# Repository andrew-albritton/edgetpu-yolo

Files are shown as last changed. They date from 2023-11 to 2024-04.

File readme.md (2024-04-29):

This repository contains all relavent information concerning the development and validation of the Smart Pest Repeller Device made by Team 30 at Texas A&M University.

Group members are Michael McNeil, Melquisedec Ordonez, and Andrew Albritton.

403 Project folder also contains all presentations from 404, and some of the research notes are not up to date. If you seek current information please read our Final Report submitted on canvas.

For Model training files please see the YOLOv5 github for the Torch versions not found in this repository.

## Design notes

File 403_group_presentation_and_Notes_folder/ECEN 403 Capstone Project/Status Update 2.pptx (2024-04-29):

## Team 30: Smart Pest Repeller Bi-Weekly Update 2 Michael McNeil Andrew Albritton Melquisedec Ordonez Sponsor: Peng Hao Huang TA: Eric Robles


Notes: Michelle

## Project Summary

Pest control methods often involve a compromise by the consumer. Consumers will often have to make the choice between methods that are highly effective with safety concerns such as pesticides, or less effective methods that are much safer like ultrasonic emitters that cover limited frequency.
The smart pest repeller is designed to offer the best of both options by using a machine learning detection program to identify what type of pest is in the target area, and then emitting the correct sound frequency in order to deter the pest from the target area.

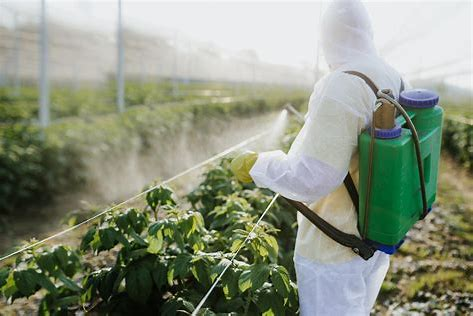
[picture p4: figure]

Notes: Kyle

## Project/Subsystem Overview

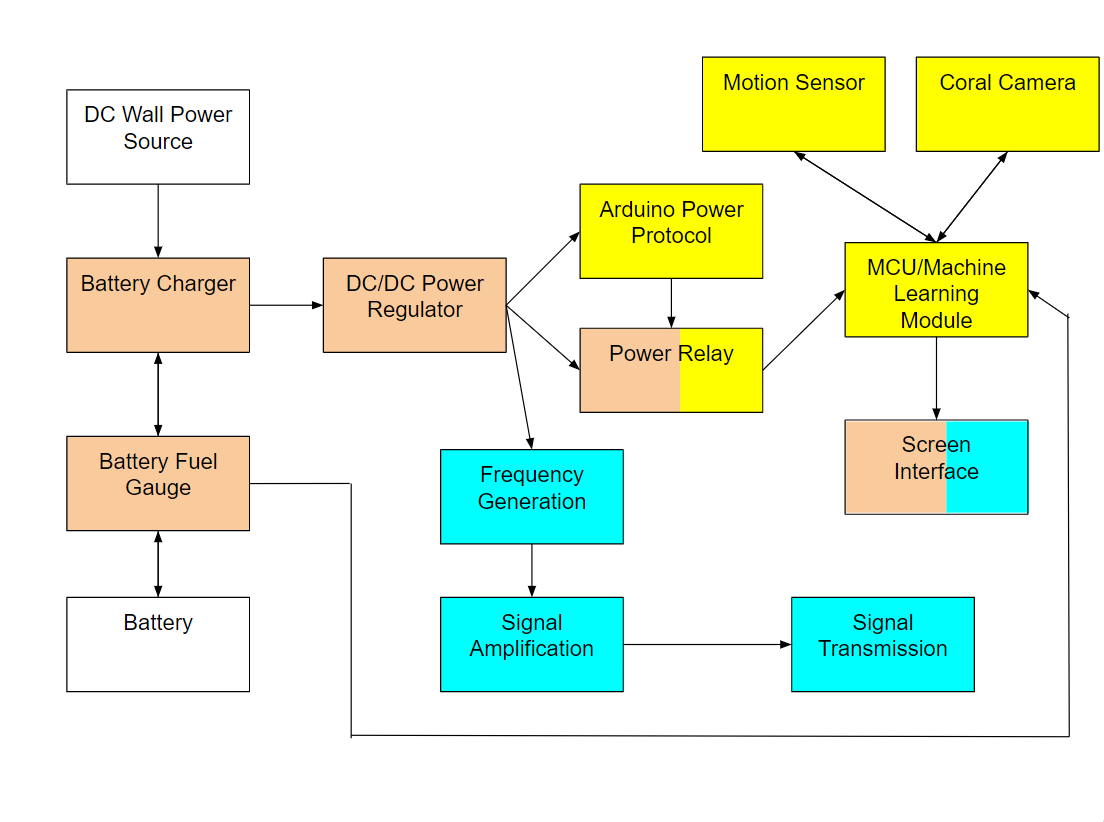
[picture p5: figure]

Michael - Orange Andrew - Yellow Mel - Blue

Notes: Eric

## Project Timeline

Subsystem Designs and Testing (to complete 2/23) | Integration of power subsystem and MCU (to complete by 2/29) | Integration of detection and emitter subsystems (to complete by 3/1) | Final Integration (to complete by 3/10) | System Test (to complete by 3/25) | Validation (to complete by 4/8) | Demo and Report (to complete by 4/15)

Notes: Eric

## Power Subsystem Michael McNeil

Accomplishments since 403 25 hrs of effort | Ongoing progress/problems and plans until the next presentation
-PCB Redesign Layout -PCB Order | PCB Assembly Subsystem Testing and Validation Start Integration with MCU

## Power Subsystem Michael McNeil

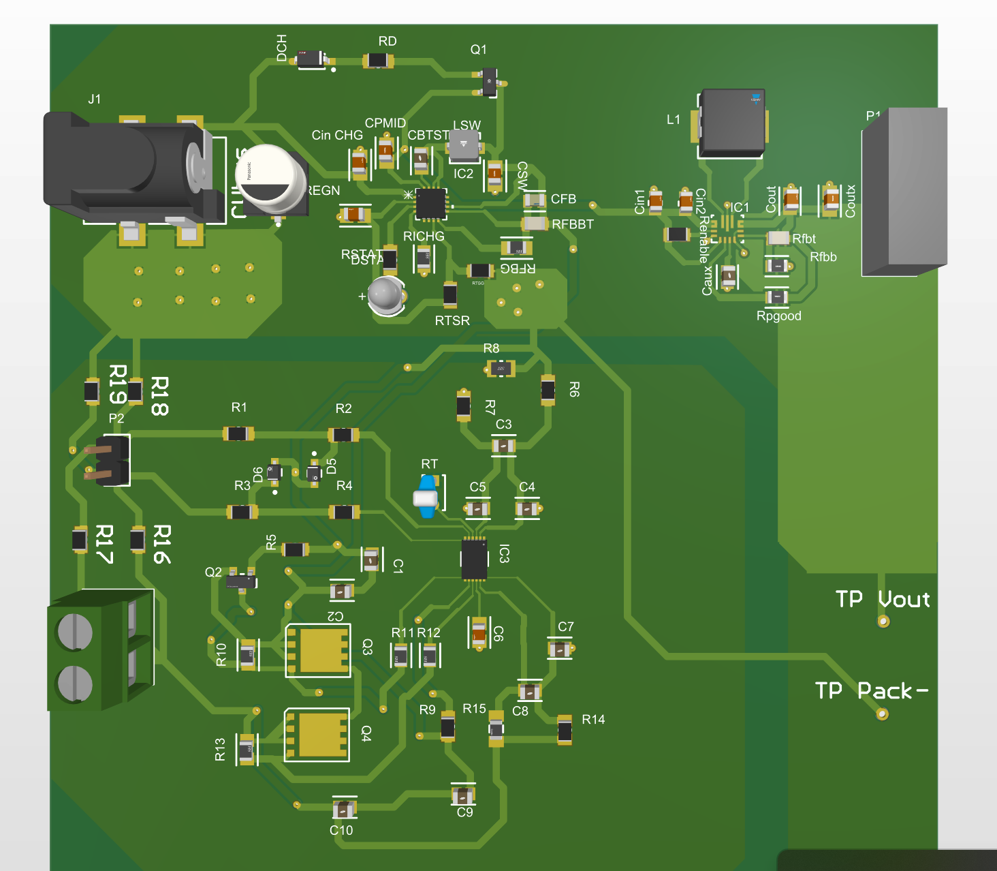
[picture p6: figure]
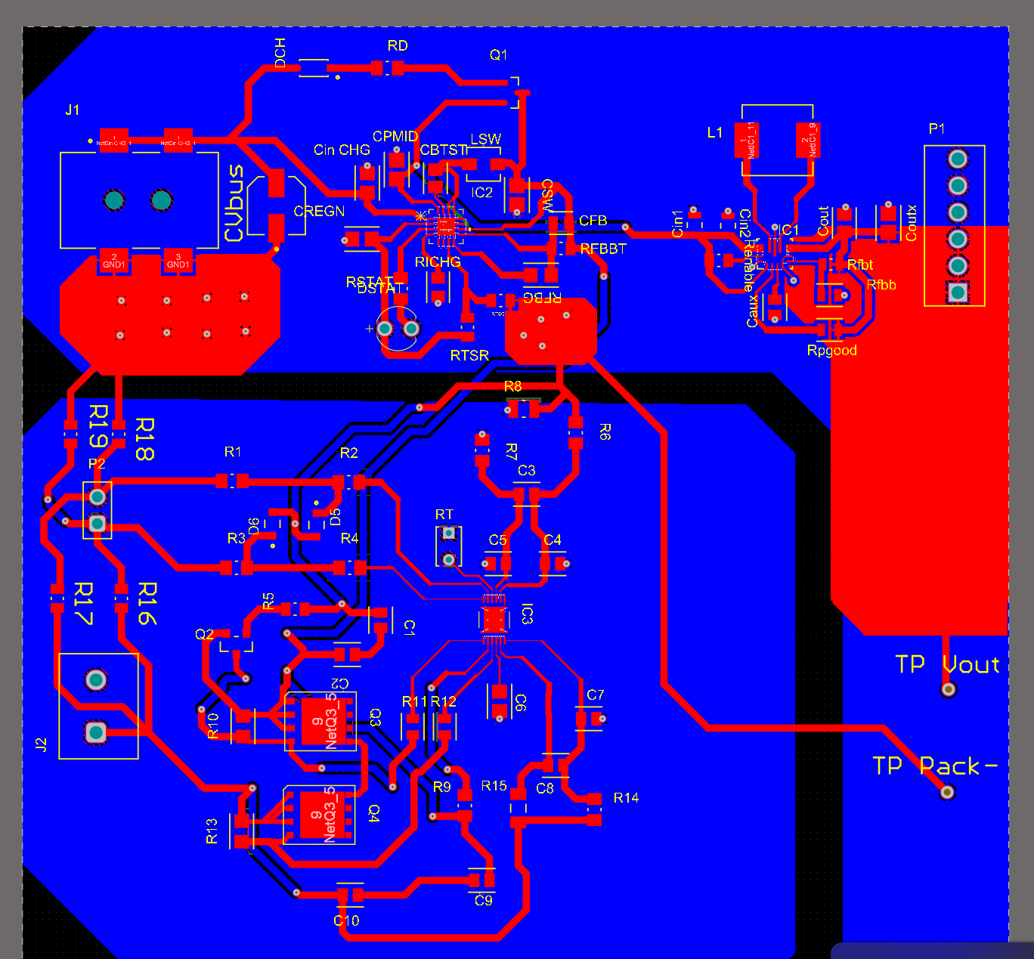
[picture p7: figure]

## ML / Control Subsystem Andrew Albritton

Accomplishments since 403 22 hrs of effort | Ongoing progress/problems and plans until the next presentation
Relay and MCU shutdown control for power system integration completed and undergoing testing Data-Set rebalanced Confusion matrix changed to integer values for more accurate validation | Model’s hyperparameters need to be adjusted in accordance with new optimizer being used. Training runs are performed over-night every day Change boot conditions of MCU, so the model will run on boot.

## ML / Control Subsystem Andrew Albritton

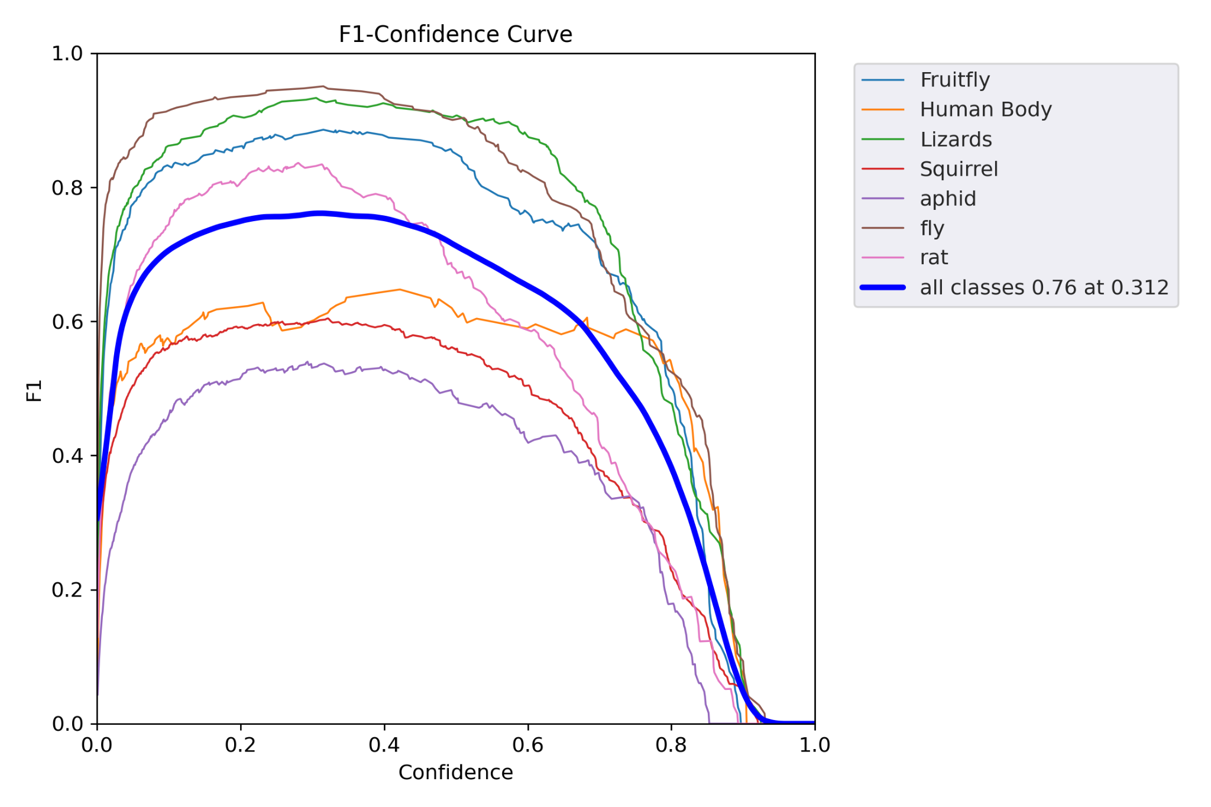
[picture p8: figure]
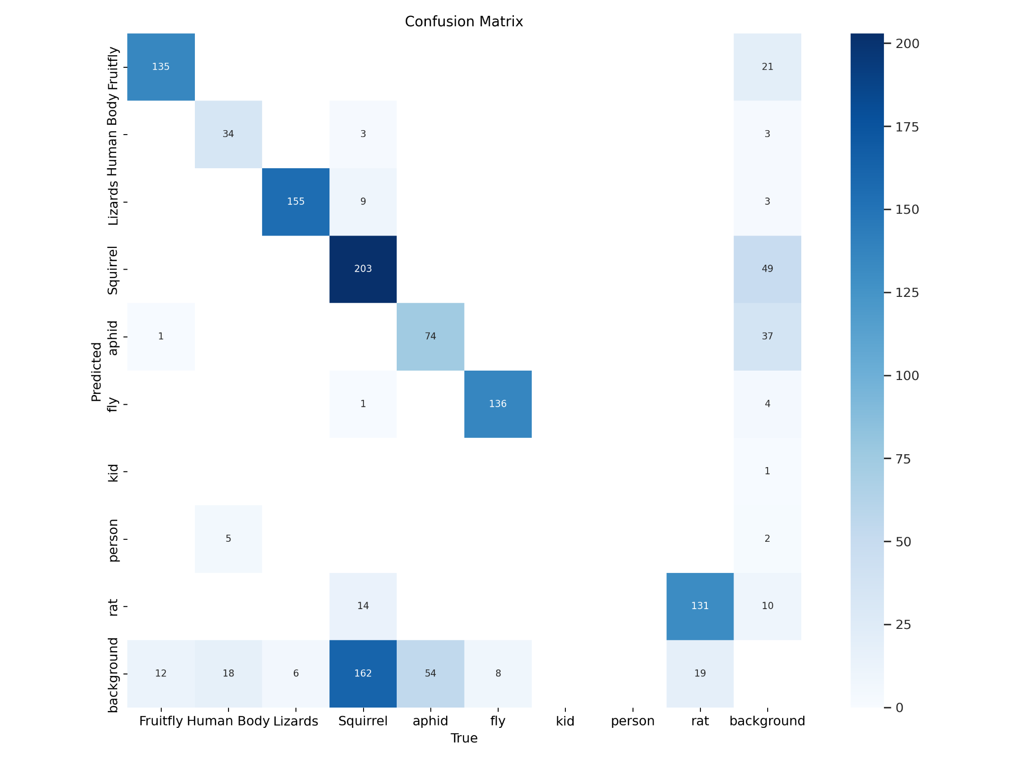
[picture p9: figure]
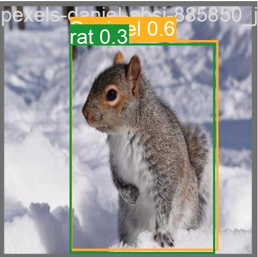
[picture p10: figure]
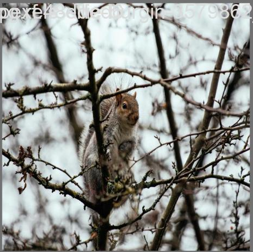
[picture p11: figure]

## Emitter Subsystem Melquisedec Ordonez

Accomplishments since 403 13 hrs of effort | Ongoing progress/problems and plans until the next presentation
Redesigned Schematic complete | Routing PCB System screen description/information Moving SPI communication to MCU

## Emitter Subsystem Melquisedec Ordonez

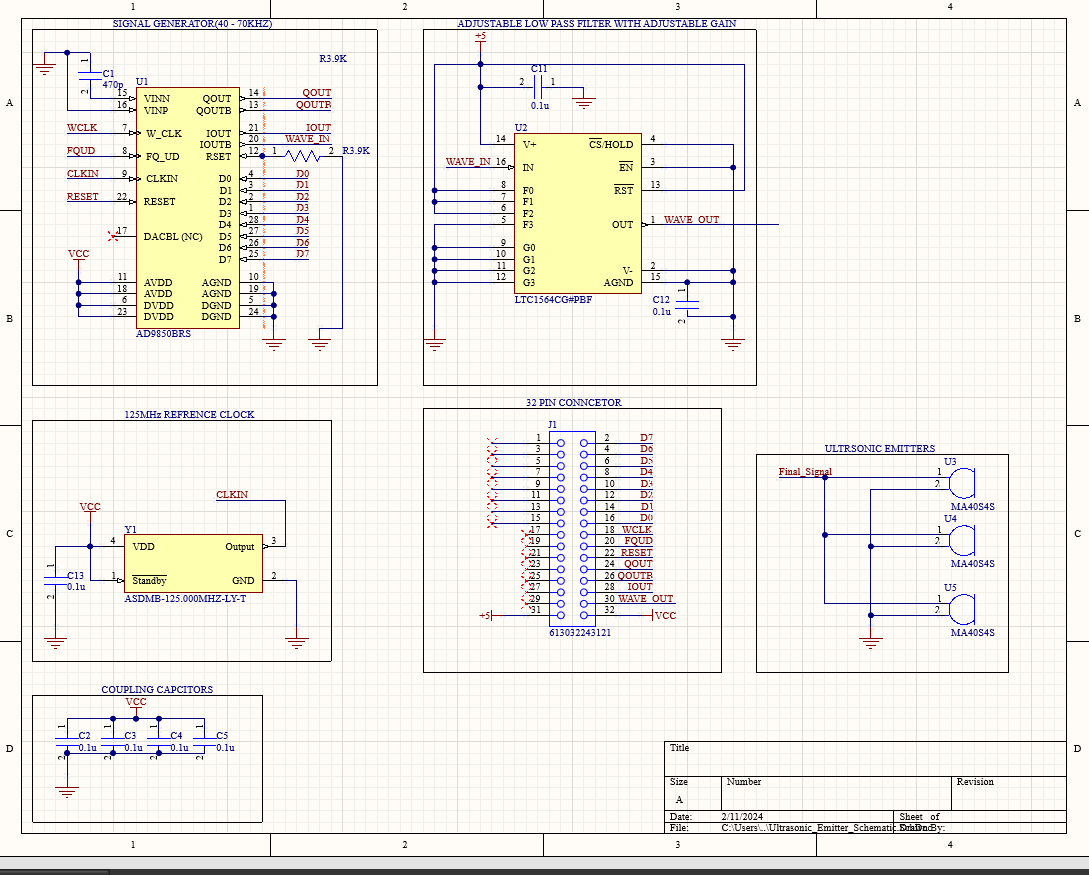
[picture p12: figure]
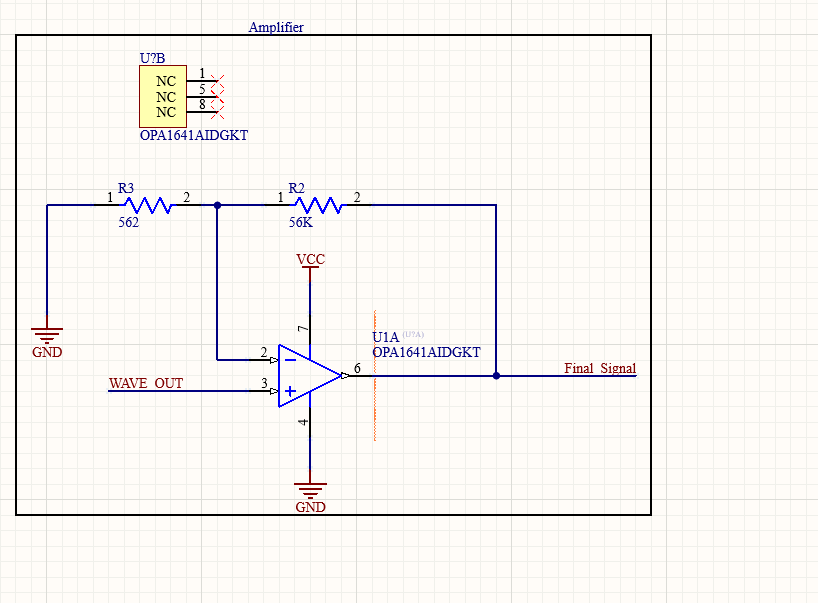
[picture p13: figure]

## Schedule

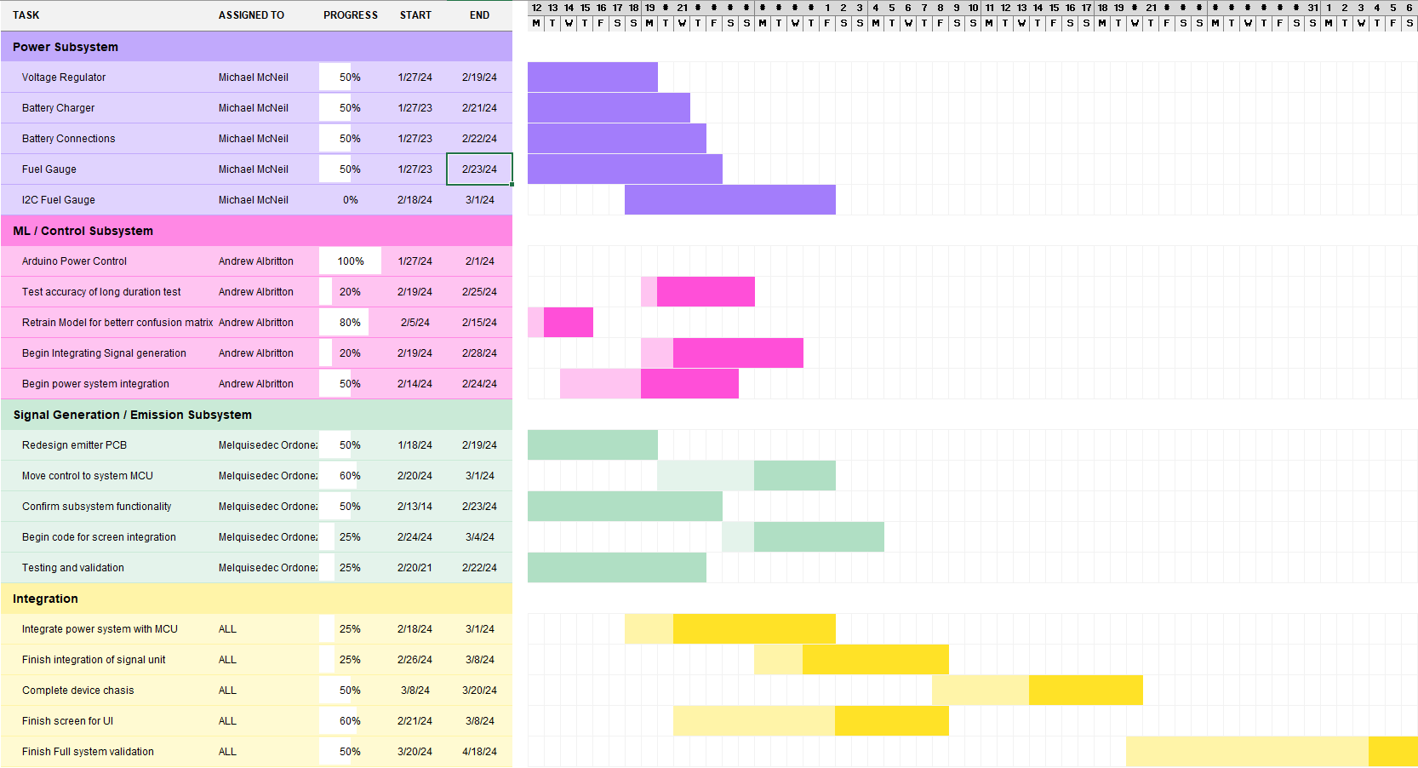
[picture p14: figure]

## Validation Plan

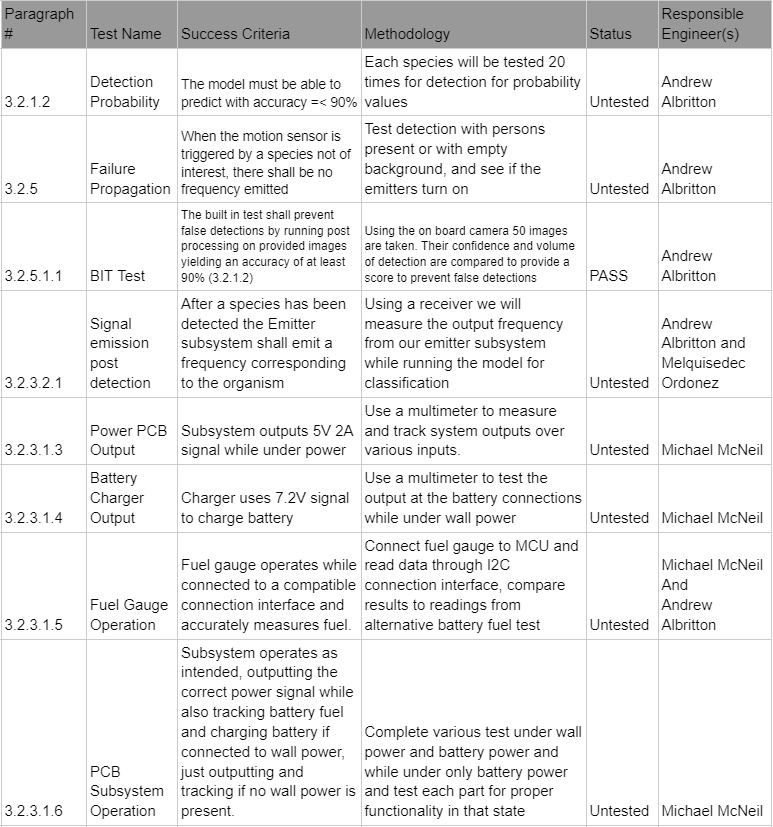
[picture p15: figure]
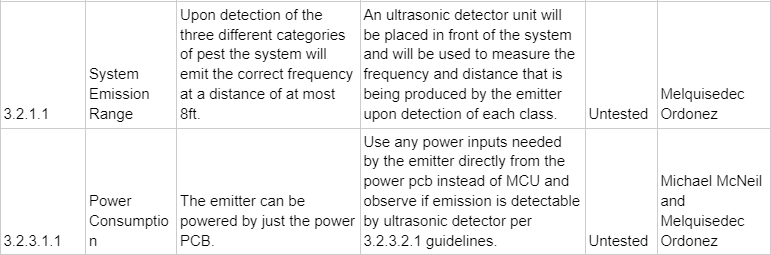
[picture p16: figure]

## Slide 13

Thank you.

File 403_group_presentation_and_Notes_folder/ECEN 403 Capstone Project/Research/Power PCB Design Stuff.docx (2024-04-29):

DC/DC Converter Start Up Simulation

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
Summary

Outline

Headings you add to the document will appear here.

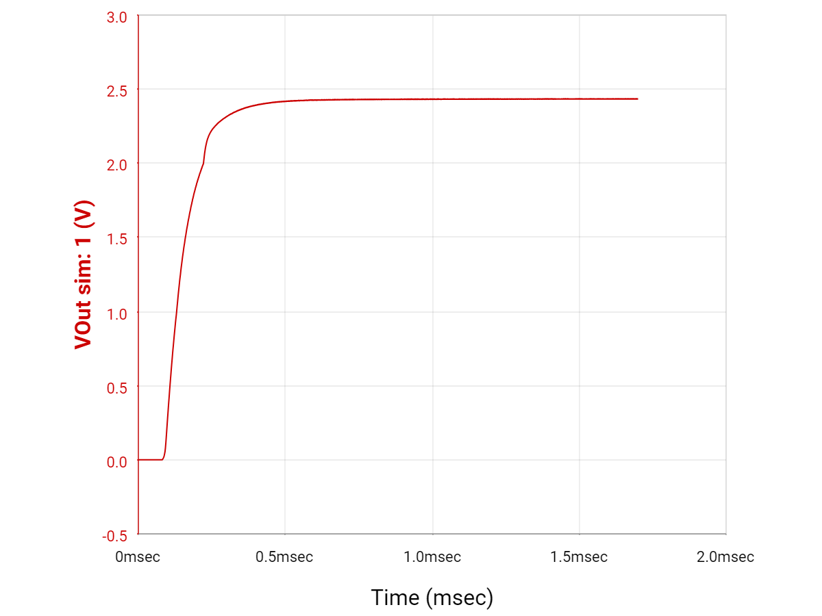
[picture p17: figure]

Start Up Time: 1.63 ms

Voltage Regulator Used for Circuit: https://www.ti.com/lit/ds/symlink/tps63070.pdf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

Battery Charger Used for Starting Design:

https://www.ti.com/lit/ds/symlink/bq24171.pdf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

DC Jack Used in Design:

https://www.cuidevices.com/product/resource/pj-002bh-smt-tr.pdf

Fuel Gauge:

https://www.ti.com/lit/ds/symlink/bq28z620.pdf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

Battery:

https://www.digikey.com/en/products/detail/jauch-quartz/LI18650JP2S2P-PCM-2-WIRES-70MM/9562752

Possible New Battery Charger -

https://www.ti.com/lit/ds/symlink/bq25306.pdf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

Fuel Gauge Technical Reference Manual - https://www.ti.com/lit/ug/sluuco9a/sluuco9a.pdf?ts=1709417492458

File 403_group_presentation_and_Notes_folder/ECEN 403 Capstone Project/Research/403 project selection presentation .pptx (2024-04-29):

## Project name: Smart Pest Repeller Team members: Andrew Albritton Michael McNeil Melquisedec Ordonez

## Executive Summary

Problem Statement:
- Pest control is a issue that often makes people choose between environmentally harmful solutions or solutions that are not very effective.
- Pest control models that do not use harmful chemicals or pesticides, often are ineffective due to the limited range of frequencies they can generate (different pests respond to different frequencies)
Solution Proposal:
- Our device will utilize an image based ML model in order to classify between three different subgroups of organisms in order to allow for repelling flies, rodents, and lizards.
- Once one of the listed organisms is recognized the sound system will emit the corresponding frequency of the recognized organism.

## Diagram of subsystems and interface

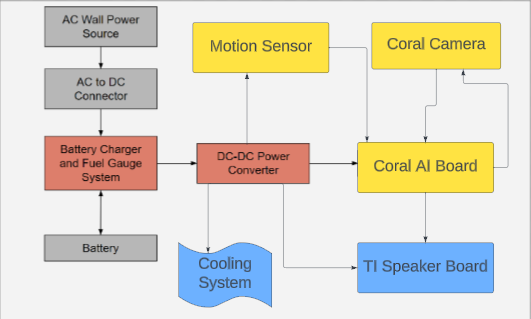
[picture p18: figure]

Red / Grey: Michael McNeil
Yellow: Andrew Albritton
Blue: Melquisedec Ordonez

## Task Partition

Andrew: ML image classification, camera operations and motion sensor
Michael: Power supply and battery system
Melquisedec: Ultrasonic emitter and cooling system

## Machine Learning Image Recognition -

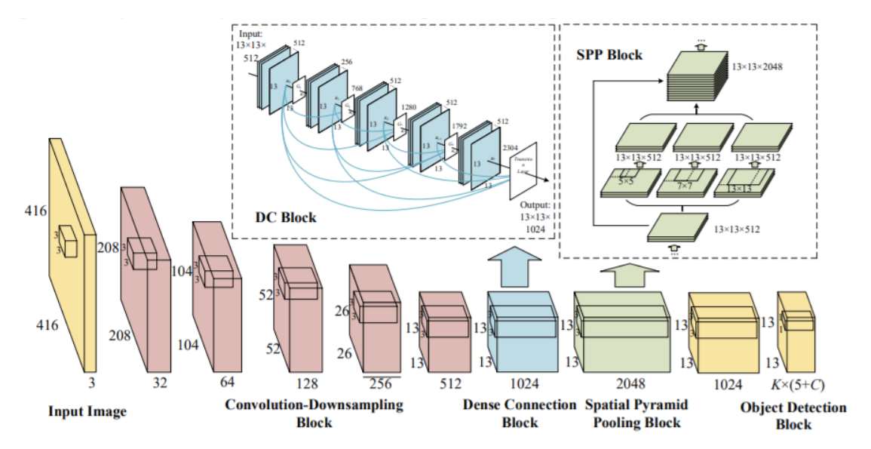
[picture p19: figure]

- A motion sensor when triggered will activate a camera attached to the Coral board.
- This image will result in one of the four following labels: Rodent, Lizard, Fly, or ignore.
- The ignore label will prevent the speakers from activating when the motion sensor is triggered by a person, dog, bird, etc.
- We will be using the YOLO git repository to create and test our model. A figure of YOLO’s algorithm can be found in the top right hand corner

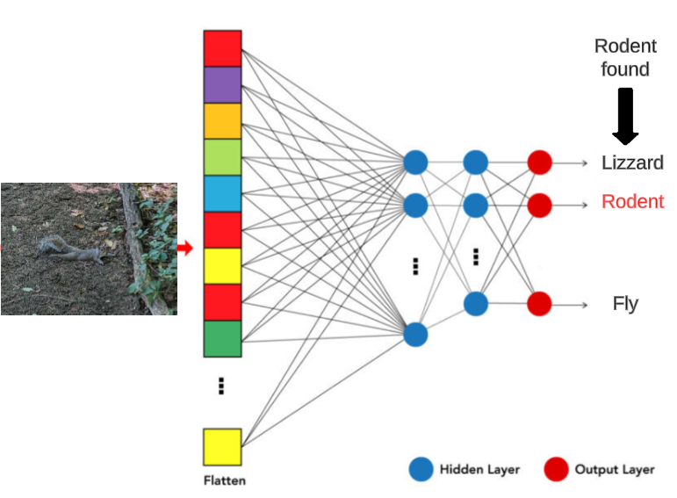
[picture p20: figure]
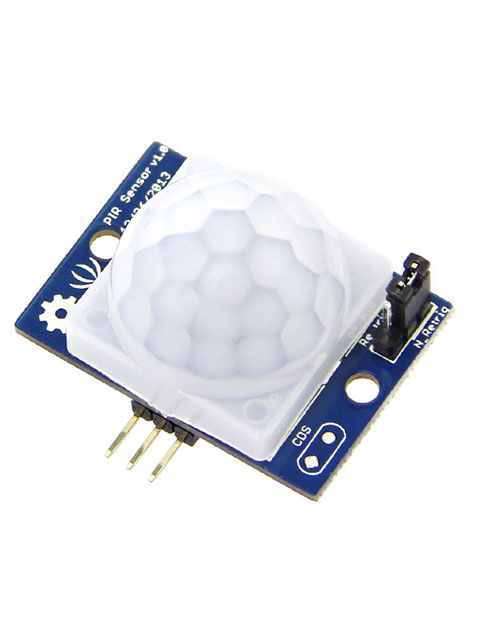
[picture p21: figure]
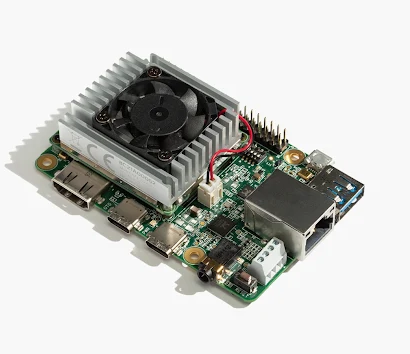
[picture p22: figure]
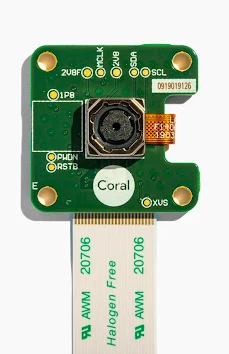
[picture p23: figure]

## Power System

Wall Power Mode:
- System, when connected to wall power, will power the main microcontrollers while charging the battery
- Battery charging circuit will monitor fuel level of battery in order to prevent overvoltage and potential damage to the battery
Battery Mode:
- System, when disconnected from wall power, will operate via battery power
- System will include a fuel gauge to indicate to user when it is time to charge the system again.

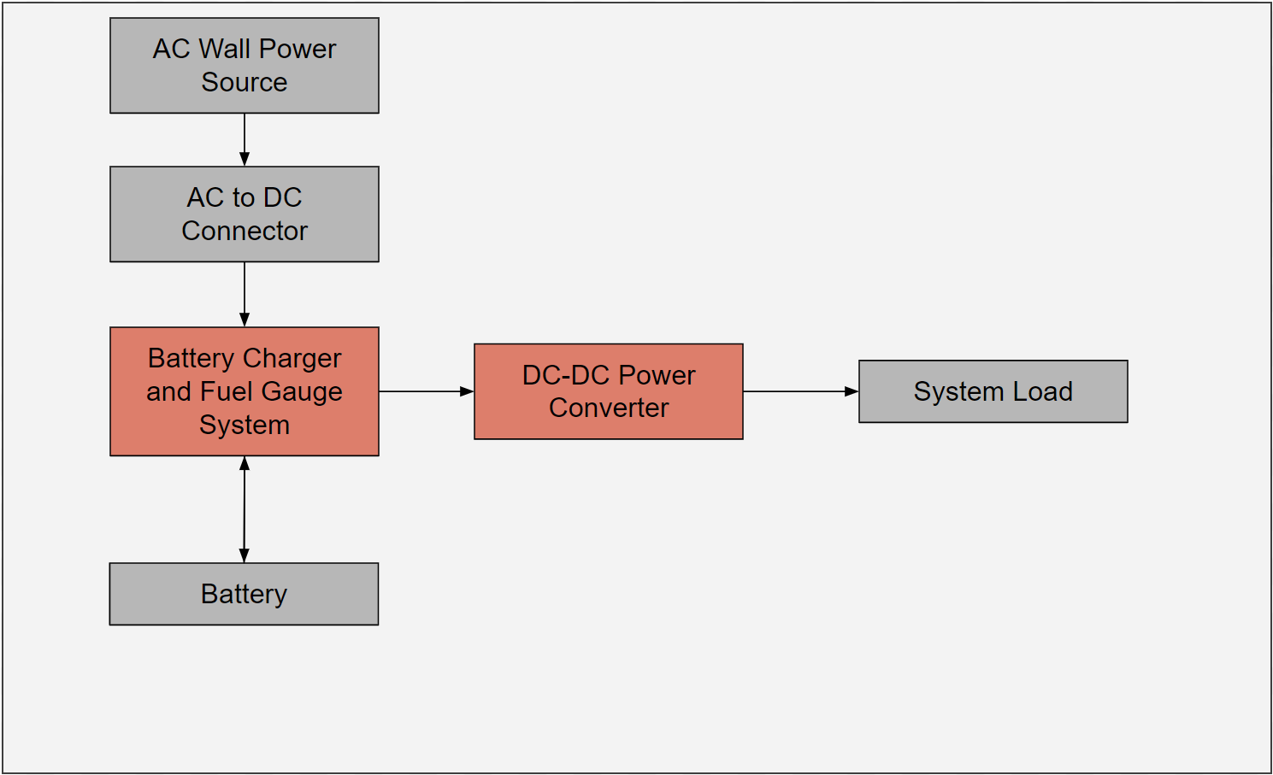
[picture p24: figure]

## Sound/Cooling System

- Transmitter emmitts ultrasonic sound sensitive to the particular pest detected by camera, eg insect or rodent.
- Humidity sensor detects when humidity levels are beyond operating range of devices
- Fan keeps system units dry to keep them operational on hotter or wet conditions.

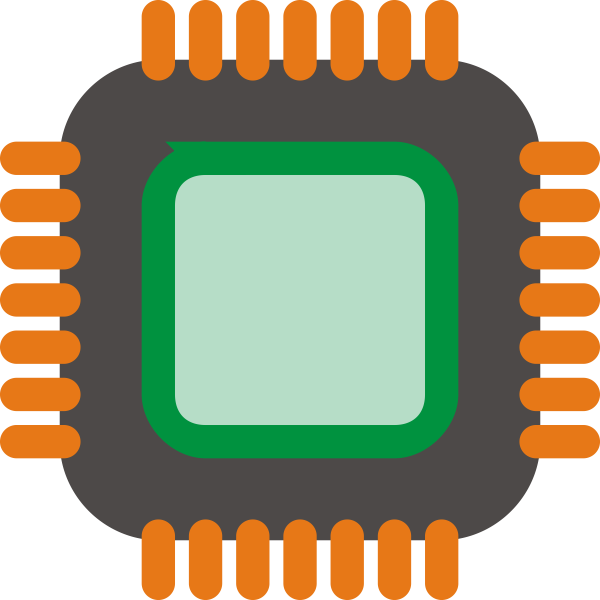
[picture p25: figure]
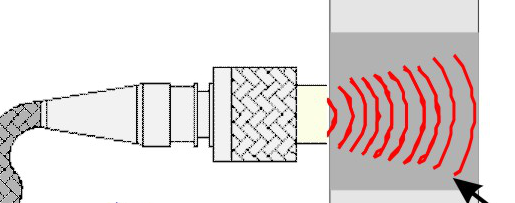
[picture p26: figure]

## Execution and Validation plan

Currently: have outlined needs for each system, assembled partial parts list, begun preliminary subsystem designs

| October 14th | October 28th | November 14th | November 25th
Machine Learning Image Model, Camera, and Motion sensor | -Finish putting together YOLO training algorithm -Start working on training | -Finish Training, and test for a goal of >=90% precision -Begin model implementation on Coral Board | -Finish Camera program .py configuration -Install Motion sensor, and test camera -Ensure proper program speed | -Finish testing the built model using the camera and motion sensor
Power Delivery / Management | -Finalize PCB Design -Run simulations -Order Parts | -Learn to solder -Start to assemble PCB circuitry | -Finish PCB implementation -Start testing and debug | -Finish test and debug -Validate system
Sound/Cooling System | - Final system parts delivered -System design completed | -Validate/Stress test individual components | -Begin on integration of individual parts | -Stress test integrated parts

## Questions?

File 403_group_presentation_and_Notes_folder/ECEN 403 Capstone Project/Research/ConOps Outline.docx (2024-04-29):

Smart Pest Repeller

Andrew Albritton

Melquisedec Ordonez

Michael McNeil

Concept of Operations

1. Executive Summary

Controlling the presence of pests is a task that can be a struggle for various different aspects of life. The goal of the Smart Pest Repeller is to address this issue as easily as possible for users while also mitigating potential hazards that come with alternative methods of pest control. The Smart Pest Repeller will utilize a camera and machine learning program in order to sense the presence of pests in the area through image processing. This will send a signal to an ultrasonic sound emitter that would activate to repel any pests that were sensed. The repeller will be able to function while plugged into a wall or on its own in order to maximize effective use situations. This will decrease the manpower and resources needed to address pest control in commercial, agricultural, and residential settings.

2. Introduction
  a. Background

The Smart Pest Repeller’s goal is to improve over what currently is the standard of the pest repellant industry, which is either the use of harsh chemicals or a similar system of ultrasonic sound that does not have an ability to detect pests, so it will always be activated and emitting sound. Some sound based repellers on the market do have sensing technology in place but none of it is image based, instead using motion sensing which will still activate in the presence of people or pets in the home or surrounding area. The Smart Pest Repeller is designed to be the environmental and pet friendly solution to pest problems.

The current standard for pest control employed by most residential or commercial users currently is either the use of pesticides and other harsh chemicals or the implementation of different ultrasonic sound systems than the Smart Pest Repeller system. The limitations and drawbacks of these methods is what we are seeking to address with the Smart Pest Repeller. Since SPR is using image processing sensing technology to identify pests, it will not activate in the presence of humans or other pets and will instead target specifically pests. This solution will mitigate the need for harsh chemical pesticides while also introducing a solution that targets specifically pests and does not act as a hindrance to anything else.

  b. Overview

The system will use a camera connected to a controller unit that will be running a program to process the images received. When the program reads that there is a pest detected in the image it will send a signal to the ultrasonic sound emitting device that will act as the pest control mechanism. Once the pest is no longer detected in the area the system will turn off the sound emitter and wait until another pest is detected. The unit will be able to plug into the wall and run directly from wall power or be able to function disconnected from the wall on battery power as well.

  c. Referenced Documents and Standards
- Rechargeable Battery Standards - Lithium, Nickel Metal Hydride, Nickel Cadmium (epectec.com) (https://www.epectec.com/batteries/battery-standards.html)
- OSHA Speaker/Workplace sound OSHA Technical Manual (OTM) - Section III: Chapter 5 | Occupational Safety and Health Administration (https://www.osha.gov/otm/section-3-health-hazards/chapter-5)
3. Operating Concept
  a. Scope

Our proposed repeller will be designed primarily for outdoor use in agricultural settings, small gardens or farms. It will be able to detect medium to larger insects in addition to smaller reptiles. The repeller will not be able to detect small insects such as mosquitos or small flies and will therefore not repel these. As our repeller will use a camera for detection it will not work at night or other times of low light visibility. The repeller will have a battery that will need to be charged so it will occasionally be limited to near the home or make use of an extension cable for uses away from the home while charging.

  b. Operational Description and Constraints

The repeller will be used outdoors in a well lit environment. The repeller will use a camera that captures an image of the environment about once every second and send it to a microcontroller. This will be sent to an image detection system that determines if there are any pests in the frame. If a pest has been identified in a frame the microcontroller will send a signal to a speaker that will emit an ultrasonic soundwave to repel the pest. Once a pest is out of frame the speaker stops emitting and waits until it receives a new signal to begin emitting again.

The smart repeller will be limited to environments with decent to high light exposure and will not work during times of low light visibility, night or moments with overcast for example.

  c. System Descriptions

The smart pest repeller will consist of three major components; the power unit, the camera and ultrasonic transmitter interface, and the microcontroller.

The power unit can operate either plugged into a traditional wall outlet or independently with a battery. While plugged into a wall outlet, the microcontroller and sensors will receive power directly from the wall and will also charge the battery if neeeded. If not connected to a wall outlet the battery will take over and send power to all the systems.

The camera is controlled by a python program on the Coral board. This program will be automated to take a photo at 1 frame per second. The microcontroller will use a ML algorithm to classify objects in the image. The four choices of classification or labels for the model will be: Flies, Lizards, Rodents, and Idle. Each time an image is done processing one of the above modes will be active.


Fig 1.1

  d. Modes of Operation

Our power system will have 2 modes of operation, wall power or battery power at 5V 2-3A draw. The rest of our system will have 4 modes of operation. Three of the modes are listed in Fig 1.1 as speakers, but the fourth mode will be an idle mode where the speaker systems are turned off. The speaker being used will be marked by an LED of color corresponding to the speaker frequency.

  e. Users

The Smart Pest Repeller could be marketed to any group of individuals from the individual homeowner to the commercial farmer. This is a great solution to pest control in small areas and could be deployed to cover much larger areas if multiple devices are used. It will act as an eco-friendly solution to the everyday pest problems that users may encounter.

  f. Support

Support for the Smart Pest Repeller will come in the form of a manual that will describe how the system works and how to operate it as well as a brief description of each subsystem in place in the system for troubleshooting purposes.

4. Scenarios
  a. Garden or Outdoor Area Use

The Smart Pest Repeller will be best suited to smaller outdoor areas or gardens. This will be an ideal location for the SPR as the camera system will have a hard time sensing pests the farther they are away so this system will be optimized for use in locations such as backyard gardens or lounge areas. The system will do great in these settings as it will likely be checked on by users more frequently than a device that is just left in the field so charging will be common enough to not be an issue. The system will also not target any pets that could be a concern for the user.

  b. Commercial Agriculture

The Smart Pest Repeller could also be used on bigger portions of land that would be used in farming operations but the amount of devices used may vary depending on the size of the land. Since the camera can only see so much in detail it will be more difficult to apply the camera sensing technology to a larger farm setting but if there are multiple systems in place that are strategically located, the system results should be similar to the results of using one device in a smaller area.

5. Analysis
  a. Summary of Proposed Improvements

The recent models of “Smart Pest Repellers” are motion based, or constantly emit high frequency sound. Our device will utilize a deep learning algorithm which will differentiate between undesirable and desirable organisms. For example, a bee pollinating your garden is desirable, while a grasshopper would damage fauna. We would want to allow bees to pollinate, but if there are undesirable organisms present we will turn the high frequency emitter on.

  b. Disadvantages and Limitations

The disadvantages of the Smart Pest Repeller system is that since the system will be constantly running a machine learning algorithm for image processing, there will be a significant increase in power needs for the system to function. The system will also be less effective at night time since it is using image processing to detect pests and at night the camera visibility will decrease drastically. The system will also be contained in a housing unit that will take up more space than the alternative solutions such as plug-ins or citronella candles.

  c. Alternatives

Many alternatives to the Smart Pest Repeller already exist on the market but each of these has different limitations of their own. Pesticides are a very common solution to the pest problem, but they also have significant drawbacks in the form of polluting the environment and also exposing unintended organisms to harmful chemicals such as other humans and pets. Other ultrasonic sound repellent systems also exist but they have limitations such as always emitting sound having to be plugged into a wall power outlet, or always emitting the same frequency (lizards, rodents, and flies react to separate frequencies: 52-60kHz, 60-72kHz, and 38-44kHz respectively)

  d. Impact

For the average gardener, our device will provide protection from not only flies, but rodents and lizards as well. We will be using our machine learning algorithm to differentiate between the animals listed above; this allows for differing frequency outputs from our sound source, allowing for effective pest control from most possible invaders. It can also be noted with other devices, organisms become accustomed to the constant presence of high frequency sound over time causing the device to lose its effectiveness. Our device will only trigger while there is a pest detected, this allows for an irregular pattern of sound, thus causing adaptation to the device to become more difficult for pests. High frequency pest control is considered one of if not the most humane method of pest control currently, and our device will allow for a broader range of application than the devices currently on the market.

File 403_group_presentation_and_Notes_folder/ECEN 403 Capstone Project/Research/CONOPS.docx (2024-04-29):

Smart Pest Repeller

Andrew Albritton

Mequisedec Ordonez

Michael McNeil

Concept of Operations

REVISION

14 September 2023

Concept of Operations

for

Smart Pest Repeller

Team 30

Approved by:

_____________________________

Project Leader Date

_____________________________

Prof. Kalafatis Date

_____________________________

T/A Date

Change Record

Rev. | Date | Originator | Approvals | Description
0 | 9/12/23 | ALL | | Draft Release
1 | 9/28/23 | ALL | | Midterm Report ICD & FSR additions

Table of Contents

Table of Contents 3

List of Tables 4

List of Figures 5

1. Executive Summary 6

2. Introduction 7

2.1. Background 7

2.2. Overview 7

2.3. Referenced Documents and Standards 7

3. Operating Concept 8

3.1. Scope 8

3.2. Operational Description and Constraints 8

3.3. System Description 8/9

3.4. Modes of Operations 9

3.5. Users 9

3.6. Support 9

4. Scenarios 9

4.1. Garden or Small Outdoor Area Use 9/10

4.2. Commercial Use……………………………………………………………………………10

5. Analysis 10

5.1. Summary of Proposed Improvements 10

5.2. Disadvantages and Limitations 10

5.3. Alternatives 10

5.4. Impact 11

List of Tables

No table of figures entries found.

List of Figures

# Fig 1.1 - Subsystem Operational Flow Chart

# 1. Executive Summary

Controlling the presence of pests is a task that can be a struggle for various different aspects of life. The goal of the Smart Pest Repeller is to address this issue as easily as possible for users while also mitigating potential hazards that come with alternative methods of pest control. The Smart Pest Repeller will utilize a camera and machine learning program in order to sense the presence of pests in the area through image processing. This will send a signal to an ultrasonic sound emitter that would activate to repel any pests that were sensed. The device will be able to function while plugged into a wall or on its own in order to maximize effective use situations. This will decrease the manpower and resources needed to address pest control in commercial, agricultural, and residential settings.

# 2. Introduction

There are many pest control options on the market. Each of these options have some negative aspects that consumers may need to consider when deciding how to approach their pest control problems. The goal of the Smart Pest Repeller is to create the best solution to these problems while mitigating potentially negative aspects of pest control.

## 2.1. Background

The current standard for pest control employed by most residential or commercial users currently is either the use of pesticides and other harsh chemicals or the implementation of different ultrasonic sound systems than the Smart Pest Repeller system. The limitations and drawbacks of these methods is what we are seeking to address with the Smart Pest Repeller. Since SPR is using image processing sensing technology to identify pests, it will not activate in the presence of humans or other pets and will instead target specific pests. This solution will mitigate the need for harsh chemical pesticides while also introducing a solution that targets specific pests and does not act as a hindrance to anything else.

## 2.2. Overview

The system will use a camera connected to a controller unit that will be running a program to process the images received. When the program reads that there is a pest detected in the image it will send a signal to the ultrasonic sound emitting device that will act as the pest control mechanism. Once the pest is no longer detected in the area the system will turn off the sound emitter and wait until another pest is detected. The unit will be able to plug into the wall and run directly from wall power or be able to function disconnected from the wall on battery power as well.

## 2.3. Referenced Documents and Standards

- Rechargeable Battery Standards - Lithium, Nickel Metal Hydride, Nickel Cadmium (epectec.com) (https://www.epectec.com/batteries/battery-standards.html)
- OSHA Speaker/Workplace sound OSHA Technical Manual (OTM) - Section III: Chapter 5 | Occupational Safety and Health Administration (https://www.osha.gov/otm/section-3-health-hazards/chapter-5)

# 3. Operating Concept

## 3.1. Scope

The proposed system will be designed primarily for outdoor use in agricultural settings, small gardens or farms. It will be able to detect medium to larger insects in addition to smaller reptiles. The camera will not be able to detect small insects such as mosquitos or small flies and will therefore not repel these. The camera will also limit when the device can be used since during night time and in low light environments visibility will be an issue for the camera used for detection. The device will have a battery that will need to be charged so it will occasionally be limited to near the home or make use of an extension cable for uses away from the home while charging.

## 3.2. Operational Description and Constraints

The repeller will be used outdoors in a well-lit environment. The repeller will use a camera that captures an image of the environment about once every second and send it to a microcontroller. This will be sent to an image detection system that determines if there are any pests in the frame. If a pest has been identified in a frame the microcontroller will send a signal to a speaker that will emit an ultrasonic soundwave to repel the pest. Once a pest is out of frame the speaker stops emitting and waits until it receives a new signal to begin emitting again.

The smart repeller will be limited to environments with decent to high light exposure and will not work during times of low light visibility, at night or moments with overcast for example.

## 3.3. System Description

The Smart Pest Repeller will consist of three major components; the power unit, the camera and ultrasonic transmitter interface, and the microcontroller.

The power unit can operate either plugged into a traditional wall outlet or independently via a rechargeable lithium-ion battery system. While plugged into a wall outlet, the system will be able to run while also charging the battery for possible wireless use in the future. If not connected to a wall outlet the battery will continue to power the system, the system will also keep track of the fuel levels of the battery and alert the user when a recharge is needed for the battery system.

The camera is controlled by a python program on the Coral board. This program will be automated to take a photo at 1 frame per second. The microcontroller will use a machine learning, ML, algorithm to classify objects in the image. The four choices of classification or labels for the model will be: Flies, Lizards, Rodents, and Idle. Each time an image is done processing one of the above modes will be active.


Fig 1.1

## 3.4. Modes of Operations

The system will have one mode of operation and that will simply be “active”. In active mode the system will continuously run the camera and take in data that will be processed in real time to see if there is a pest present. Once the system detects a pest in the target area the emitter will turn on in order to remove pests from the area. Once the camera no longer detects the presence of pests, the system will turn off the emitter and continue to monitor for pests in the target area.

## 3.5. Users

The Smart Pest Repeller could be marketed to any group of individuals from the individual homeowner to the commercial farmer. This is a great solution to pest control in small areas and could be deployed to cover much larger areas if multiple devices are used. It will act as an eco-friendly solution to the everyday pest problems that users may encounter.

## 3.6. Support

Support for the Smart Pest Repeller will come in the form of a manual that will describe how the system works and how to operate it as well as a brief description of each subsystem in place in the system for troubleshooting purposes.

# 4. Scenario(s)

## 4.1. Garden or Small Outdoor Area Use

The Smart Pest Repeller will be best suited to smaller outdoor areas or gardens. This will be an ideal location for the SPR as the camera system will have a hard time sensing pests the further they are away so this system will be optimized for use in locations such as backyard gardens or lounge areas. The system will do great in these settings as it will likely be checked on by users more frequently than a device that is just left in the field so charging will be common enough to not be an issue. The system will also not target any pets that could be a concern for the user.

## 4.2. Commercial Agriculture

The Smart Pest Repeller could also be used on bigger portions of land that would be used in farming operations but the amount of devices used may vary depending on the size of the land. Since the camera can only see so much in detail it will be more difficult to apply the camera sensing technology to a larger farm setting but if there are multiple systems in place that are strategically located, the system results should be similar to the results of using one device in a smaller area.

# 5. Analysis

## 5.1. Summary of Proposed Improvements

The recent models of “Smart Pest Repellers” are motion based, or constantly emit high frequency sound. Our device will utilize a machine learning algorithm which will differentiate between undesirable and desirable organisms. For example, a bee pollinating your garden is desirable, while a grasshopper would damage fauna. We would want to allow bees to pollinate, but if there are undesirable organisms present we will turn the high frequency emitter on.

## 5.2. Disadvantages and Limitations

The disadvantages of the Smart Pest Repeller system is that since the system will be constantly running a machine learning algorithm for image processing, there will be a significant increase in power needs for the system to function. The system will also be less effective at night time since it is using image processing to detect pests and at night the camera visibility will decrease drastically. The system will also be contained in a housing unit that will take up more space than the alternative solutions such as plug-ins or citronella candles.

## 5.3. Alternatives

Many alternatives to the Smart Pest Repeller already exist on the market but each of these has different limitations of their own. Pesticides are a very common solution to the pest problem, but they also have significant drawbacks in the form of polluting the environment and also exposing unintended organisms to harmful chemicals such as other humans and pets. Other ultrasonic sound repellent systems also exist but they have limitations such as always emitting, sound having to be plugged into a wall power outlet perpetually, or always emitting the same frequency (lizards, rodents, and flies react to separate frequencies: 52-60kHz, 60-72kHz, and 38-44kHz respectively)

## 5.4. Impact

For the average gardener, our device will provide protection from not only flies, but rodents and lizards as well. We will be using our machine learning algorithm to differentiate between the animals listed above; this allows for differing frequency outputs from our sound source, allowing for effective pest control from most possible invaders. It can also be noted with other devices, organisms become accustomed to the constant presence of high frequency sound over time causing the device to lose its effectiveness. Our device will only trigger while there is a pest detected, this allows for an irregular pattern of sound, thus causing adaptation to the device to become more difficult for pests. High frequency pest control is considered one of if not the most humane method of pest control currently, and our device will allow for a broader range of application than the devices currently on the market.

Calibrated LWIR Raw Video Data Collection - Gold Standard – Test 1 Revision -

Concept of Operations Revision Smart Pest Repeller

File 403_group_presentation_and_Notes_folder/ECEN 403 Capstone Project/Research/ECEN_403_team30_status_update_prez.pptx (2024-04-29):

## Project name: Smart Pest Repeller Team members: Andrew Albritton Michael McNeil Melquisedec Ordonez

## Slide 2

Team 30: Smart Pest Repeller


System Block Diagram:
Andrew Albritton: Yellow (ML Algorithm / Emitter Control)
Michael McNeil: Red / Grey (Power Delivery / Battery Charging)
Melquisedec Ordonez: Blue (Emitter Subsystem)

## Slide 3

ML Algorithm / Control Andrew Albritton

Accomplishments since the last presentation 38 hrs 45 min | Ongoing progress/problems and plans until the next presentation
-training data acquired (9 classes and 9468 images labeled) -image resizing tool (any size to 640x640) -trained model (loss <= .02 and cls loss < .005) -detection testing (probability of detection varies) -model outputs found labels and probabilities of detection to .csv format for processing - Change model platform from pyTorch to Tensorflow Lite (coral board TPU compatible) | - Control program (image grab -> image processing -> .csv from model -> processing .csv -> send GPI/O control) - Camera / Motion sensor operation programs - Coral Board boot settings must be changed to immediately run control program


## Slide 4

Power Supply PCB Michael McNeil

Accomplishments since the last presentation ~30 hrs | Ongoing progress/problems and plans until the next presentation
Power PCB parts selected Battery Charger schematic complete Battery Fuel Gauge schematic complete | Finish Placing and Routing PCB in Altium PCB assembly PCB Circuit testing


## Signal Generator / Emitter

Melquisedec Ordonez

Accomplishments Since the last presentation ~20 Hrs | Ongoing progress/problems and plans until then next presentation
Signal Generator Schematic design complete Final Parts List complete | PCB design and routing Signal Generation and testing


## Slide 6

Team 30: Smart Pest Repeller - Schedule


## Team 30: Smart Pest Repeller Validation Plan

Task | Specification | Result | Owner
Training Verification | Goal of 90%>= precision or Goal of .1 >= loss | PASS | Andrew
Camera Verification | make sure 3 photos are taken per second | | Andrew
Motion Verification | Ensure camera activates from motion control | | Andrew
Camera MLA processing verification | Ensure precision is maintained post- implementation (Generalization of model usually yields 10-20% lower probability of detection) | | Andrew
DC/DC Voltage Converter Verification | Verify that converter can take in various input voltages and continue to output 5V and 2A | | Michael
Battery Charger Verification | Verify battery charger charges battery | | Michael
Fuel Gauge Indicator Verification | Verify fuel gauge tracks fuel and indicates when batteries need to charge | | Michael
Power PCB Verification | Verify PCB circuit connects and system functions as intended | | Michael
Signal Verification | Establish signal generator can produce the three separate frequencies required | | Mel
Amplifier Verification | Verify signal is appropriately amplified before reaching emitter | | Mel
Emitter verification | Make sure emitter can emit required frequencies | | Mel
Emitter PCB verification | Verify circuit behaves like individually verified componentes did | | Mel

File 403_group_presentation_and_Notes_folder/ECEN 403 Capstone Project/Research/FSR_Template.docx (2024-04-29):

Smart Pest Repeller

Andrew Albritton

Michael McNeil

Melquisedec Ordonez

Functional System Requirements

REVISION – Draft

25 September 2023

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
Summary

Outline

Introduction

Purpose and Scope

Responsibility and Change Authority

Applicable and Reference Documents

Applicable Documents

YOLOv5 GitHub

Reference Documents

Smart Ultrasonic Insects & Pests Repeller for Farms & Inventories Purpose

Humidity management of outdoor electronic equipment: methods, pitfalls, and recommendations

Order of Precedence

Requirements

System Definition

Characteristics

Functional / Performance Requirements

Variable Pest Responses

Search Probability of Detection

Image Classification Distance

Physical Characteristics

Volume Envelope

Mounting

Electrical Characteristics

Inputs

Power Consumption

Input Voltage Level

Outputs

Data Output

Diagnostic Output

Wiring

Environmental Requirements

Thermal

Rain

Humidity

Failure Propagation

Failure Detection, Isolation, and Recovery (FDIR)

Built In Test (BIT)

3.2.5.1.2 BIT False Alarms

Appendix A: Acronyms and Abbreviations

Appendix B: Definition of Terms

Functional System Requirements

for

Smart Pest Repeller

Prepared by:

_____________________________

Author Date

Approved by:

_____________________________

Project Leader Date

_____________________________

John Lusher, P.E. Date

_____________________________

T/A Date

Change Record

Rev. | Date | Originator | Approvals | Description
0 | 9/25/23 | ALL | | Draft Release

Table of Contents

Table of Contents 26

List of Tables 27

List of Figures 28

1. Introduction 29

1.1. Purpose and Scope 29

1.2. Responsibility and Change Authority 29

2. Applicable and Reference Documents 30

2.1. Applicable Documents 30

2.2. Reference Documents 30

2.3. Order of Precedence 31

3. Requirements 32

3.1. System Definition 32

3.2. Characteristics 33

3.2.1. Functional / Performance Requirements 33

3.2.1.1. Variable Pest Responses 33

3.2.1.2. Search Probability of Detection 33

3.2.1.3. Image Classification Distance 33

3.2.2. Physical Characteristics 34

3.2.2.1. Volume Envelope 34

3.2.2.2. Mounting 34

3.2.3. Electrical Characteristics 35

3.2.3.1. Inputs 35

3.2.3.1.1. Power Consumption 35

3.2.3.1.2. Input Voltage Level 35

3.2.3.2. Outputs 36

3.2.3.2.1. Data Output 36

3.2.3.2.2. Diagnostic Output 36

3.2.3.3. Wiring 36

3.2.4. Environmental Requirements 37

3.2.4.1. Thermal 37

3.2.4.2. Rain 37

3.2.4.3. Humidity 37

3.2.5. Failure Propagation 38

3.2.5.1. Failure, Detection, Isolation, and Recovery 38

3.2.5.1.1. Built In Test (BIT) 38

3.2.5.1.2. BIT False Alarms 38

Appendix A Acronyms and Abbreviations 39

Appendix B Definition of Terms 40

Schedule 43

Validation Plan 44

List of Tables

Table 1. Subsystem Assignments 7

List of Figures

Figure 1. Project Conceptual Image 1

Figure 2. Block Diagram of System 4

# 1. Introduction

## 1.1. Purpose and Scope

The purpose of this document is to describe the system requirements for our assigned project. Our assigned project’s purpose is to provide an alternative solution for high frequency based pest control. Current pest control models only target one subset of organisms (IE: rodents, flies, or larger mammals), our device shall be able to target a range of organisms including: flies, rodents, and lizards. The system shall output a specific frequency corresponding with the found organism. This frequency will cause organisms to vacate the effective area of the transmitter.

Figure 1 shows a conceptual finished product as proposed in the CONOPS report.


Figure 1. Project Conceptual Image

## 1.2. Responsibility and Change Authority

The team leader, Melquisedec Ordonez, will be responsible for ensuring that all requirements are met. These requirements can be changed with the approval of the team leader and sponsor Peng Hao Huang.

Subsystem | Assigned Member
Power Supply and Battery System | Michael McNeil
Machine Learning Algorithm, Motion Sensor, and Camera Interface | Andrew Albritton
Signal Generation and Transmission | Melquisedec Ordonez

Table 1: Subsystem Assignments

# 2. Applicable and Reference Documents

## 2.1. Applicable Documents

The following documents, of the exact issue and revision shown, form a part of this specification to the extent specified herein:

Document Number | Revision/Release Date | Document Title
ultralytics/yolov5: YOLOv5 🚀 in PyTorch > ONNX > CoreML > TFLite (github.com) (https://github.com/ultralytics/yolov5/tree/master) | 22 November 2022 | a. YOLOv5 GitHub
978-1-5090-0917-6 | 16-19th October 2016 | An Overview of the Fundamentals of Battery Chargers
G950-01455-01 | December 2022 | Coral Dev Board Datasheet

## 2.2. Reference Documents

The following documents are reference documents utilized in the development of this specification. These documents do not form a part of this specification and are not controlled by their reference herein.

Document Number | Revision/Release Date | Document Title
978-1-5386-5368-5 | 28-29th December 2018 | b. Smart Ultrasonic Insects & Pests Repeller for Farms & Inventories Purpose
1910.305 | 16 January 1981 | Wiring methods, components, and equipment for general use.
1521-3331 | March 2002 | c. Humidity management of outdoor electronic equipment: methods, pitfalls, and recommendations

## 2.3. Order of Precedence

In the event of a conflict between the text of this specification and an applicable document cited herein, the text of this specification takes precedence without any exceptions.

All specifications, standards, exhibits, drawings or other documents that are invoked as “applicable” in this specification are incorporated as cited. All documents that are referred to within an applicable report are considered to be for guidance and information only, except ICDs that have their relevant documents considered to be incorporated as cited.

# 3. Requirements

This section defines the minimum requirements that the development item(s) must meet. The requirements and constraints that apply to performance, design, interoperability, reliability, etc., of the system, are covered.

## 3.1. System Definition

The Smart Pest Repeller will run from power supplied via a battery or wall power. While in operation it will be monitoring for any possible pest activity. Once a pest is detected the ML algorithm will process the image and see if the organism present falls into one of the preset categories created for the program. If the organism is identified as belonging to one of those groups, then the emitter will output the corresponding frequency of sound until the system no longer detects the pest.


Figure 2. Block Diagram of System

Describe the block diagram, what are the subsystems, how do they interconnect. Someone reading this section should get a general idea of what you are building, why, and how it will solve the problem you are solving.

The power supply and battery system will ensure that the pest repeller system will be able to work while connected to a wall power source or on its own. While connected to the wall power source the system will use the wall power as the main source of power while charging the batteries via the battery charger circuit. The charging circuit will monitor the battery as it charges, ensuring that the battery does not over charge and potentially suffer damage. While the system receives power from the battery source the fuel gauge will monitor the batteries fuel levels. Once the battery fuel level reaches a point where the system needs to charge again soon, the system will have a light indicator to tell the user that the system needs to charge. The power system will also incorporate a DC to DC converter in order to ensure the voltage being sent to the microcontroller is consistent and usable at around 5 volts and 2 amps of output. Once motion is detected the photo taken by our Coral AI camera will be sent to the Coral AI dev board for image processing. This processing shall be done using an image recognition ML model.

The transmitter shall emit frequencies of: 38-44 kHz, 52-60 kHz, and 60-72 kHz. The emitter will receive its signal from a direct digital synthesizer(DDS). It will generate the unique signal for the pest in question and deliver it to the emitter for transmission. The signal is then amplified as needed for the emitter. Only one emitter and therefore one frequency will be used at a time. For multiple pests in the frame of the camera the repeller will target one pest until it is out of frame. The emitter will then emit a new frequency for the remaining pest(s) until all pests are out of frame of the camera.

## 3.2. Characteristics

### 3.2.1. Functional / Performance Requirements

#### 3.2.1.1. Signal Emission Amplification

The system will amplify the emitter's three required ranges of frequencies at a minimum of 7V/V.

Rationale: Signal coming from the emitter will be low and will need to be amplified to reach a wider distance.

#### 3.2.1.2. Search Probability of Detection

The Smart Pest Repeller classification subsystem shall have a probability of 90% of detection.

Rationale: Most image classification algorithms settle to 85-93% after extensive training, so our goal will be to reach a slightly above average detection rate.

#### 3.2.1.3. Image Classification Distance

The Smart Pest Repeller shall have a classification distance of a maximum of 8ft for rodents / large lizards. Classification distance for small organisms may vary depending on given size (ie: fruit flies <2ft). Minimum distance of classification for larger organisms shall be 2ft.

Rationale: The image classification model being used will have a larger chance of guessing the correct species, when said organism takes up greater space on camera. Organisms can also be too close, taking up too much space in the image, preventing classification.

### 3.2.2. Physical Characteristics

This is the area where you will specify any requirements regarding the physical characteristics of your system. Does the system need to not have a mass/weight higher than X, etc.? There are examples shown below…

#### 3.2.2.1. Volume Envelope

The system shall have a maximum size of 6x6x14in, or the size of a shoe box. This box shall have openings allowing for image and motion sensing, as shown in figure 1. The mass of the system shall not exceed 10kg.

Rationale: The size and mass will allow for deployment of the system to take place by hand.

#### 3.2.2.2. Mounting

The mounting height of the Smart Pest Repeller will be at a height of 2 ½ ft from the ground.

Rationale: This will ensure proper image quality for processing and reduce possible classification errors.

### 3.2.3. Electrical Characteristics

#### 3.2.3.1. Inputs

d. The presence or absence of any combination of the input signals in accordance with ICD specifications applied in any sequence shall not damage the Smart Pest Repeller, reduce its life expectancy, or cause any malfunction, either when the unit is powered or when it is not.
e. No sequence of command shall damage the Smart Pest Repeller, reduce its life expectancy, or cause any malfunction.
f. Motion sensor input shall be utilized to trigger the device’s camera to take a photo.

Rationale: By design, should limit the chance of damage or malfunction by user/technician error. Also, motion detection should limit the need for constant data processing, saving power usage.

##### 3.2.3.1.1 Power Consumption

The maximum peak power of the system shall not exceed 15 watts.

Rationale: This is a requirement in order to achieve the desired battery life outlined by the sponsor

##### 3.2.3.1.2 Input Voltage Level

The input voltage to the entire system will be a 120 Volt AC signal from a wall outlet.

Rationale: This allows the system to work via wall power

#### 3.2.3.2. Outputs

##### 3.2.3.2.1 Data Output

The smart pest repeller shall output frequencies corresponding with the output of the Coral AI board. The Coral AI board shall output three different control signals to trigger the speaker system.

Rationale: The smart pest repeller must output the corresponding frequency to the found pest in order to have effective pest control.

##### 3.2.3.2.2 Diagnostic Output

The Smart Pest Repeller shall have an led marking when the battery needs to be charged.

Rationale: Provides the ability to know when the device will need to utilize wall power.

#### 3.2.3.3. Wiring

The Smart Pest Repeller shall follow guidelines provided in document 1910.305 for wiring standards.

Rationale: Conform to equipment for general use standard of OSHA guidelines

### 3.2.4. Environmental Requirements

The Smart Pest Repeller System shall be designed to withstand and operate in the environments and laboratory tests specified in the following section.

Rationale: The device must be able to function consistently outdoors.

#### 3.2.4.1. Thermal

The smart pest repeller shall be able to function in a temperature range of 0℃-40℃

Rationale: Average outdoor temperature within the United States falls within the range shown above.

#### 3.2.4.2. Rain

The Smart Pest Repeller shall function in light rain, while it is suggested that the device be taken inside during flooding.

Rationale: The device should function in light rain but if there is a risk of the power cord being submerged in water or having contact with water, the device should be brought inside to prevent unwanted shorts.

#### 3.2.4.3. Humidity

We will be adhering to the IEEE standard for humidity and outdoors circuits in document 1521-3331.

### 3.2.5. Failure Propagation

The Smart Pest Repeller shall not activate its high frequency transmitters on false activation of motion sensor.

#### 3.2.5.1. Failure Detection, Isolation, and Recovery (FDIR)

##### 3.2.5.1.1 Built In Test (BIT)

The Smart Pest Repeller image recognition shall have a label marked ignore when the three labels provided (fly, rodent, or lizard) have a low confidence margin or are not triggered. This test will be run three times to ensure detection before triggering an output.

Rational: This test will assist in lowering false triggers of the device when nothing is present, or when a person/dog triggers the motion sensor

###### 3.2.5.1.1.1 3.2.5.1.2 BIT False Alarms

False alarm rate shall be no more than 10%.

Rationale: Error of the model will be around 10%, but checking over three different iterations will allow for results to be averaged and compared, allowing for mitigated false alarms below 10%.

# h. Appendix A: Acronyms and Abbreviations

AC Alternating Current

DDS Direct Digital Synthesizer

DC Direct Current

GPIO General Purpose In-Out port

Hz Hertz

MCU Microcontroller unit

ML Machine Learning

MLA Machine Learning Algorithm

BIT Built-In Test

ICD Interface Control Document

kHz Kilohertz (1,000 Hz)

LED Light-emitting Diode

mA Milliamps

mW Milliwatts

PCB Printed Circuit Board

TBD To Be Determined

# i. Appendix B: Definition of Terms

DC-DC converter: A circuit or device capable of sending a current from one voltage level to another, higher or lower than the original, input, signal.

Direct Digital Synthesizer: A device capable of producing a digital signal, typically sinusoidal, and converting it into an analog one.

(Ultrasonic) Emitter: A device, typically based on crystals and using the piezoelectric effect, that is able to take an electrical signal and convert it into an audio signal; can be an ultrasound signal as well.

Image Processing: The process of converting a digital image and separating it into bits of useful information that aids in a larger process, eg. recognizing certain traffic signals for autonomous driving vehicles.

Machine Learning: The use of computers to perform specific tasks without explicit instructions from a user. Instead the computer is given a set of models and statistical tools that it uses to extract and analyze data to perform desired action(s) on its own.

Microcontroller: a, typically small, integrated circuit that is able to control a certain set(s) of operation(s). Unlike a full personal computer a microcontroller is not required to run on an operating system.

Functional System Requirements Revision - 0 Project Name: Smart Pest Repeller

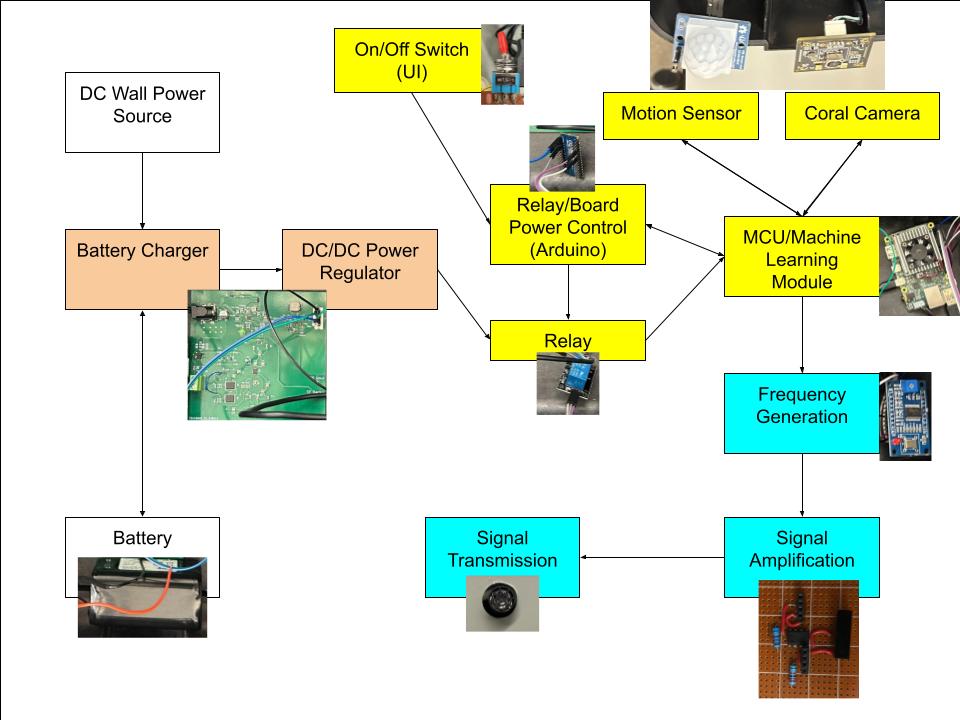
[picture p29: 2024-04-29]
403_group_presentation_and_Notes_folder/ECEN 403 Capstone Project/Research/Updated System Diagram 1_25.jpg

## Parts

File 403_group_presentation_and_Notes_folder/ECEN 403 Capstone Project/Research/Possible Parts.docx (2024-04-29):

Camera

Camera datasheet | Coral (https://coral.ai/docs/camera/datasheet/) *** decided

Microsoft Word - HM01B0-MNA-00FT870_DS_preliminary_v01 (Ltd.)_FX01FF-608H-1-20191114.docx (digikey.com) (https://mm.digikey.com/Volume0/opasdata/d220001/medias/docus/4886/HM01B0-MNA-00FT870.pdf)

Camera Algorithm help

Accurate detection and identification of insects from camera trap images with deep learning | PLOS Sustainability and Transformation (https://journals.plos.org/sustainabilitytransformation/article?id=10.1371/journal.pstr.0000051)

tensorflow - How to embed/deploy an arbitrary machine learning model on microcontrollers? - Artificial Intelligence Stack Exchange (https://ai.stackexchange.com/questions/25775/how-to-embed-deploy-an-arbitrary-machine-learning-model-on-microcontrollers)

Possible Micro Controller

Data Sheet (nuvoton.com) (https://www.nuvoton.com/export/resource-files/DS_M0A21_M0A23_Series_EN_Rev1.01.pdf)

(we need a MCU with SPC and integrated graphics) the one above does not contain graphics

Dev Board datasheet | Coral (https://coral.ai/docs/dev-board/datasheet/) ***decided

Motion Sensor

101020060 Seeed Technology Co., Ltd | Development Boards, Kits, Programmers | DigiKey (https://www.digikey.com/en/products/detail/seeed-technology-co.,-ltd/101020060/5487425)

Speaker info

Rats to 60-72 kHz. Insects like Mosquitoes, Flies hate frequencies around 38-44 kHz.

(lizards, rodents, and flies react to separate frequencies: 52-60kHz, 60-72kHz, and 38-44kHz respectively)

Assessment of short-term exposure to an ultrasonic rodent repellent device | The Journal of the Acoustical Society of America | AIP Publishing (https://pubs.aip.org/asa/jasa/article/144/4/2501/598840/Assessment-of-short-term-exposure-to-an-ultrasonic)

Ultrasonic Frequencies For Repelling Insects & PestsBack ButtonSearch IconFilter Icon (electroschematics.com) (https://www.electroschematics.com/ultrasound-and-insects/)

CUSA-TR50-05-2000-W68 Datasheet - Ultrasonic Transceivers | Ultrasonic Sensors | CUI Devices (https://www.cuidevices.com/product/resource/cusa-tr50-05-2000-w68.pdf) -56kHz

Ultrasonic Xmtr 40khz 120db - 255-400ST16-ROX (electromaker.io) (https://www.electromaker.io/shop/product/ultrasonic-xmtr-40khz-120db)

BOOSTXL-TUSS4470 Ultrasonic Transducer EVM - TI | Mouser (https://www.mouser.com/new/texas-instruments/ti-boostxl-tuss4470-evaluation-module/)

400ST/R160 (mouser.com) (https://www.mouser.com/datasheet/2/911/T400S16-1369697.pdf) Mfr. Part #400SR16M (https://www.mouser.com/ProductDetail/Pro-Wave-Electronics/400SR16M?qs=gTYE2QTfZfQyvQRhg8yGxA%3D%3D)

web (mouser.com) (https://www.mouser.com/datasheet/2/911/T400S10-1369632.pdf) Mfr. Part #400SR10P (https://www.mouser.com/ProductDetail/Pro-Wave-Electronics/400SR10P?qs=gTYE2QTfZfS2JpP4EseLOw%3D%3D) - 40kHz

PUI audio UTR-1440K-TT transducer ←– probably this one(center frequency 40KHz)

Signal generator

AD9850 DDS

Battery - https://www.digikey.com/en/products/detail/jauch-quartz/LI18650JP2S2P-PCM-2-WIRES-70MM/9562752

Pest Research- https://www.electroschematics.com/ultrasound-and-insects/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,38-44%20kHz%208%20Lizards%3A%2052-60%20kHz%20More%20items

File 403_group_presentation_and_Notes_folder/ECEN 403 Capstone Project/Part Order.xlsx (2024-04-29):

Order Date | Part Number | Item Name | Where To Buy | Cost per Part | Quantity | Total Cost | Item Description
2023-10-24 | GRM155R61E105KA12D | Capacitor | https://www.mouser.com/ProductDetail/Murata-Electronics/GRM155R61E105KA12D?qs=hiffU4J9V6bE4a81t2Mv5A%3D%3D | 0.025 | 10 | 0.25 | 1 uF Capacitor
2023-10-24 | CL05A104KA5NNNC | Capacitor | https://www.mouser.com/ProductDetail/Samsung-Electro-Mechanics/CL05A104KA5NNNC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 | 0.006 | 20 | 0.12 | 100 nF Capacitor
2023-10-24 | GRM21BR61C106KE15K | Capacitor | https://www.mouser.com/ProductDetail/Murata-Electronics/GRM21BR61C106KE15K?qs=h0WOCFF19ULjTOS37upAEw%3D%3D | 0.063 | 10 | 0.63 | 10 uF Capacitor
2023-10-24 | GCM155R71C473KA37D | Capacitor | https://www.mouser.com/ProductDetail/Murata-Electronics/GCM155R71C473KA37D?qs=QDXoN8f0aYLB89MfqGWy7Q%3D%3D | 0.027 | 10 | 0.27 | 0.047 uF Capacitor
2023-10-24 | CL05B104KO5NNNC | Capacitor | https://www.mouser.com/ProductDetail/Samsung-Electro-Mechanics/CL05B104KO5NNNC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 | 0.013 | 10 | 0.13 | 100nF Capacitor
2023-10-24 | GRM155C81E225KE11D | Capacitor | https://www.mouser.com/ProductDetail/Murata-Electronics/GRM155C81E225KE11D?qs=I53XXhTNm8tFQfVNTleWgg%3D%3D | 0.072 | 10 | 0.72 | 2.2 uF Capacitor
2023-10-24 | GRM155R71C104KA88D | Capacitor | https://www.mouser.com/ProductDetail/Murata-Electronics/GRM155R71C104KA88D?qs=8YPuuxuUzMJKePo9sU3A2g%3D%3D | 0.015 | 10 | 0.15 | 0.1 uF Capacitor
2023-10-24 | C3216X5R1V226M160AC | Capacitor | https://www.mouser.com/ProductDetail/TDK/C3216X5R1V226M160AC?qs=NRhsANhppD8TwN31eZ1xGQ%3D%3D | 0.92 | 5 | 4.6 | 22uF Capacitor
2023-10-24 | GRM32ER61C476KE15L | Capacitor | https://www.mouser.com/ProductDetail/Murata-Electronics/GRM32ER61C476KE15L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 | 0.9 | 3 | 2.7 | 47 uF Capacitor
2023-10-24 | C1608X5R1A106K080AC | Capacitor | https://www.mouser.com/ProductDetail/TDK/C1608X5R1A106K080AC?qs=NRhsANhppD%252B2Bx3rv7OLbA%3D%3D | 0.35 | 3 | 1.05 | 10uF Capacitor
2023-10-24 | BAT165-HG3_H | Schottky Diode | https://www.mouser.com/ProductDetail/Vishay-Semiconductors/BAT165-HG3-H?qs=tlsG%2FOw5FFivO%2Fxptk7cKQ%3D%3D | 0.37 | 5 | 1.85 | Schottky Diode
2023-10-24 | LTST-C191KSKT | LED | https://www.mouser.com/ProductDetail/Lite-On/LTST-C191KSKT?qs=%252BOwCA7JpThkCRw1w23EPng%3D%3D | 0.27 | 3 | 0.81 | LED Light
2023-10-24 | MM3Z5V6C | Zener Diode | https://www.mouser.com/ProductDetail/onsemi-Fairchild/MM3Z5V6C?qs=rXqtSHp76q6mZxise9dftg%3D%3D | 0.2 | 5 | 1 | 5.6V Zener Diode
2023-10-24 | PJ-002BH-SMT-TR | DC Jack | https://www.mouser.com/ProductDetail/CUI-Devices/PJ-002BH-SMT-TR?qs=WyjlAZoYn53o41yWl%252Bm9HQ%3D%3D | 1.31 | 2 | 2.62 | DC Jack
2023-10-24 | 1778764 | Terminal Block | https://www.mouser.com/ProductDetail/Phoenix-Contact/1778764?qs=i0qWf6NAoDsxsSJGIXIgDA%3D%3D | 0.78 | 3 | 2.34 | 2 Port Terminal Block
2023-10-24 | 2355091-3 | Wire Header | https://www.mouser.com/ProductDetail/TE-Connectivity/2355091-3?qs=4ASt3YYao0WWRl2qxnHLIA%3D%3D | 0.67 | 2 | 1.34 | 3 Port Wire Header
2023-10-24 | IHLP2525CZER1R5M01 | Inductor | https://www.mouser.com/ProductDetail/Vishay-Dale/IHLP2525CZER1R5M01?qs=rvfpa0%252BU10MsoAwz5IOlCA%3D%3D | 1.06 | 2 | 2.12 | 1.5 uH Inductor
2023-10-24 | IHLP1212BZER3R3M11 | Inductor | https://www.mouser.com/ProductDetail/Vishay-Dale/IHLP1212BZER3R3M11?qs=e2ByEPnK0Ig%252BAjrbnwehhQ%3D%3D | 1.1 | 2 | 2.2 | 3.3 uH Inductor
2023-10-24 | CSD17581Q3A | MOSFET | https://www.mouser.com/ProductDetail/Texas-Instruments/CSD17581Q3A?qs=%2FP2Ij7fVdhEBu0ceoVBClg%3D%3D | 0.78 | 5 | 3.9 | N Channel Power MosFet
2023-10-24 | FDN336P | MOSFET | https://www.digikey.com/en/products/detail/onsemi/FDN336P/965302 | 0.43 | 2 | 0.86 | P Channel MosFet
2023-10-24 | 2N7002K | MOSFET | https://www.mouser.com/ProductDetail/onsemi-Fairchild/2N7002K?qs=iS%252BvaFGfLorx0keKeEIrfg%3D%3D | 0.34 | 2 | 0.68 | N Channel MosFet
2023-10-24 | RC0402FR-0710RL | Resistor | https://www.mouser.com/ProductDetail/YAGEO/RC0402FR-0710RL | 0.013 | 10 | 0.13 | 10 Ohm Resistor
2023-10-24 | RC0402FR-07232KL | Resistor | https://www.mouser.com/ProductDetail/YAGEO/RC0402FR-07232KL?qs=UOUeRUa%252B8WnjPzjgDm%252BAVg%3D%3D | 0.009 | 10 | 0.09 | 232k Ohm Resistor
2023-10-24 | RC0402FR-0732K4L | Resistor | https://www.mouser.com/ProductDetail/YAGEO/RC0402FR-0732K4L?qs=UOUeRUa%252B8WnB0qTAKiXUGg%3D%3D | 0.009 | 10 | 0.09 | 32.4k Ohm Resistor
2023-10-24 | RC0402FR-07100KL | Resistor | https://www.mouser.com/ProductDetail/YAGEO/RC0402FR-07100KL?qs=mnq%2FyloZIXzTlUn7JAHSWg%3D%3D | 0.009 | 10 | 0.09 | 100k Ohm Resistor
2023-10-24 | RC0402FR-0722K1L | Resistor | https://www.mouser.com/ProductDetail/YAGEO/RC0402FR-0722K1L?qs=w93zFNUZ2uDvEtSz4JNhRg%3D%3D | 0.009 | 10 | 0.09 | 22.1k Ohm Resistor
2023-10-24 | RC0402FR-071ML | Resistor | https://www.mouser.com/ProductDetail/YAGEO/RC0402FR-071ML?qs=V1yeUXFNrknfoI4987wfBQ%3D%3D | 0.009 | 10 | 0.09 | 1 M Ohm Resistor
2023-10-24 | RC0402FR-072K2L | Resistor | https://www.mouser.com/ProductDetail/YAGEO/RC0402FR-072K2L?qs=YUgVZYePFqCtk4LkRUkHoA%3D%3D | 0.009 | 10 | 0.09 | 2.2K Ohm Resistor
2023-10-24 | RC0402FR-076K8L | Resistor | https://www.mouser.com/ProductDetail/YAGEO/RC0402FR-076K8L?qs=V1yeUXFNrkmX0EPng%252BcJrA%3D%3D | 0.009 | 10 | 0.09 | 6.8K Ohm Resistor
2023-10-24 | RC0402FR-131K5L | Resistor | https://www.mouser.com/ProductDetail/YAGEO/RC0402FR-131K5L?qs=UOUeRUa%252B8Wm%2F3wsFM0tWoA%3D%3D | 0.009 | 10 | 0.09 | 1.5K Ohm Resistor
2023-10-24 | RC0402FR-074K02L | Resistor | https://www.mouser.com/ProductDetail/YAGEO/RC0402FR-074K02L?qs=dFi98NjgUQY%252BaYZ%252BRXfKEw%3D%3D | 0.009 | 10 | 0.09 | 4.02K Ohm Resistor
2023-10-24 | RC0402FR-071KL | Resistor | https://www.mouser.com/ProductDetail/YAGEO/RC0402FR-071KL?qs=V1yeUXFNrknDEmWLmm5v6g%3D%3D | 0.009 | 10 | 0.09 | 1K Resistir
2023-10-24 | RC0402FR-07100RL | Resistor | https://www.mouser.com/ProductDetail/YAGEO/RC0402FR-07100RL?qs=V1yeUXFNrknwaJOOZ4yDtg%3D%3D | 0.009 | 10 | 0.09 | 100 Ohm Resistor
2023-10-24 | CRCW201010M0JNEF | Resistpr | https://www.mouser.com/ProductDetail/Vishay-Dale/CRCW201010M0JNEF?qs=2dg6B%2FSVtKSGHLQzdh3IBA%3D%3D | 0.25 | 5 | 1.25 | 10M Ohm Resistor
2023-10-24 | ERA-3AEB512V | Resistor | https://www.mouser.com/ProductDetail/Panasonic/ERA-3AEB512V?qs=XhO1W%252B5LdJ%252BNpOZSjywNAQ%3D%3D | 0.139 | 10 | 1.39 | 5.1k Resistor
2023-10-24 | RC0402FR-0710KL | Resistor | https://www.mouser.com/ProductDetail/YAGEO/RC0402FR-0710KL?qs=I1mnnYJTTsxUoNwrUsQExA%3D%3D | 0.009 | 10 | 0.09 | 10K Ohm Resistor
2023-10-24 | RMCF0805FT4R99 | Resistor | https://www.digikey.com/en/products/detail/stackpole-electronics-inc/RMCF0805FT4R99/1713121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 | 0.024 | 10 | 0.24 | 4.99 Ohm Resistor
2023-10-24 | RL1220T-R010-J | Resistor | https://www.mouser.com/ProductDetail/Susumu/RL1220T-R010-J?qs=nCAm%252BcMdy9zSRp8k2J0L2A%3D%3D | 0.16 | 10 | 1.6 | 10m Resistor
2023-10-24 | RC0402FR0710K | Resistor | https://www.mouser.com/ProductDetail/YAGEO/RC0402FR-0710KL?qs=I1mnnYJTTsxUoNwrUsQExA%3D%3D | 0.009 | 10 | 0.09 | 10K Resistor
2023-10-24 | RC0402FR-07249KL | Resistor | https://www.mouser.com/ProductDetail/YAGEO/RC0402FR-07249KL?qs=CGh%2FACcVdWh8MrxZHvHPdw%3D%3D | 0.009 | 10 | 0.09 | 249K Ohm Resistor
2023-10-24 | RC0603FR-07100KL | Resistor | https://www.mouser.com/ProductDetail/YAGEO/RC0603FR-07100KL?qs=e1ok2LiJcmaihem8Va5%2Fsw%3D%3D | 0.011 | 10 | 0.11 | 100k Ohm Resistor
2023-10-24 | RC0603FR-07523KL | Resistor | https://www.mouser.com/ProductDetail/YAGEO/RC0603FR-07523KL?qs=TkC2zyCLazpzUFWuXe7EHg%3D%3D | 0.011 | 10 | 0.11 | 523K Ohm Resistor
2023-10-24 | RC0402JR-072RL | Resistor | https://www.mouser.com/ProductDetail/YAGEO/RC0402JR-072RL?qs=Is6ZsIPfHkaKZvltKAB%252BEw%3D%3D | 0.01 | 10 | 0.1 | 2 Ohm Resistor
2023-10-24 | CRCW0603100KFKEA | Resistor | https://www.mouser.com/ProductDetail/Vishay-Dale/CRCW0603100KFKEA?qs=6dqgS%252BKntICWHMMdIzt5%2FQ%3D%3D | 0.019 | 10 | 0.19 | 100K Ohm Resistor
2023-10-24 | 103AT-2 | Thermistor | https://www.mouser.com/ProductDetail/Semitec/103AT-2?qs=wgO0AD0o1vvcDzsKguD%252Bew%3D%3D | 0.84 | 2 | 1.68 | 10K Thermistor
2023-10-24 | ERT-J0EM103J | Thermistor | https://www.mouser.com/ProductDetail/Panasonic/ERT-J0EM103J?qs=9gtMhpKs0nGW19HT%252BT%2Fhzg%3D%3D | 0.1 | 3 | 0.3 | NTC Thermistor Chip
2023-10-24 | TPS630701RNMR | Voltage Regulator | https://www.mouser.com/ProductDetail/Texas-Instruments/TPS630701RNMR?qs=LuYMPh7GGMTyE4ON9PhzXw%3D%3D | 2.7 | 2 | 5.4 | Voltage Regulator
2023-10-24 | BQ24171RGYR | Battery Charger | https://www.mouser.com/ProductDetail/Texas-Instruments/BQ24171RGYR?qs=QtI0yD1FyONv8pYlJaCp5g%3D%3D | 2.84 | 2 | 5.68 | Battery Charger
2023-10-24 | BQ28Z620DRZR | Battery Fuel Gauge | https://www.mouser.com/ProductDetail/Texas-Instruments/BQ28Z620DRZR?qs=3Rah4i%252BhyCHmiL1YWVaWZQ%3D%3D | 4.16 | 2 | 8.32 | Battery Fuel Gauge
2023-10-24 |  | 12 V Wall Power Plug | https://www.amazon.com/Adapter-Charger-Replacement-Regulated-Transformer/dp/B0852HX9HV?hvadid=80127002044383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 | 11.99 | 1 | 11.99 | 12V 2A DC Wall Power Plug In
2023-10-24 | G950-01455-01 | Coral AI Dev Board 1GB | G950-01455-01 Coral | Mouser (https://www.mouser.com/ProductDetail/Coral/G950-01455-01?qs=u16ybLDytRZzoDDKD3Sj%2FQ%3D%3D) | 135.35 | 1 | 135.35 | Coral AI Dev Board 1 GB
2023-10-24 | 426-FIT0729 | DFRobot camera | FIT0729 DFRobot | Mouser (https://www.mouser.com/ProductDetail/DFRobot/FIT0729?qs=pUKx8fyJudAziiVTS3YO4w%3D%3D) | 39.9 | 1 | 39.9 | Cameras & Camera Modules 8 Megapixels USB Camera (with Microphone)
2023-10-24 | AD9850BRS | DDS | https://www.mouser.com/ProductDetail/Analog-Devices/AD9850BRS?qs=BpaRKvA4VqFOcujWQ7CinQ%3D%3D | 38.6 | 1 | 38.6 | Signal Generator
2023-10-24 | 613032243121 | Connector | https://www.newark.com/wurth-elektronik/613032243121/connector-header-32pos-2-54mm/dp/85AC2511?CMP=AFC-OP | 2.88 | 1 | 2.88 | dip connector
2023-10-24 | ASDMB-125.000MHZ-LY-T | Crystal oscilator | https://www.newark.com/abracon/asdmb-125-000mhz-ly-t/mems-oscillator-125mhz-smd-2-5/dp/51AC8828 | 4.39 | 1 | 4.39 | 125MHz refrence clock
2023-10-24 | Murata MA40S4S | Ultrsonic emitter | https://www.mouser.com/ProductDetail/Murata-Electronics/MA40S4R?qs=dyqxRLCA4pZFklOm9zYjlw%3D%3D | 5.44 | 3 | 16.32 | 40Khz emitter
2023-10-24 | LTC1564CG#PBF | Filter | https://www.mouser.com/ProductDetail/Analog-Devices/LTC1564CGPBF?qs=hVkxg5c3xu%252BQPly2iwOCxQ%3D%3D | 20.66 | 1 | 20.66 | Variable low pass filter
2023-10-24 | C0603C471K5RACTU | capacitor | https://www.mouser.com/ProductDetail/KEMET/C0603C471K5RACTU?qs=IOmzgBZuQP7dAoUXUkLBEA%3D%3D | 0.028 | 10 | 0.28 | 470pf capacitor
2023-10-24 | CL21F10 | capacitor | https://www.mouser.com/ProductDetail/Samsung-Electro-Mechanics/CL21F104ZAANNNC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 | 0.025 | 10 | 0.25 | 0.1uf capacitor
2023-10-24 | ERJ-1GNJ392C | resistor | https://www.mouser.com/ProductDetail/Panasonic/ERJ-1GNJ392C?qs=wTZ%2FFzl837ZJDYKmonxusg%3D%3D | 0.027 | 10 | 0.17 | 3.9K ohm resistor
PCB Order |  |  |  | Cost | Quantity | Total Cost | Dimensions
2023-10-26 |  | Power PCB (Rev. 2) | https://cart.jlcpcb.com/quote/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 | 30.8 | 1 | 30.8 | 152.3x101.6
2023-10-27 |  | PCB Emitter(Rev. 2) | https://cart.jlcpcb.com/quote/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 | 7 | 1 | 7 | 2.38x3.16 inches
 |  |  |  |  |  | Total Cost
 |  |  |  |  |  | 366.69
 |  |  |  |  |  | Budget Left
 |  |  |  |  |  | 33.31

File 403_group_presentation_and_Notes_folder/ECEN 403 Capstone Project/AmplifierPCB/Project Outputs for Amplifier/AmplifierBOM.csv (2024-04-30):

Comment | Description | Designator | Footprint | LibRef | Quantity
22nF | Cap Ceramic 22nF 50V C0G 5% Pad SMD 0805 +125°C Automotive T/R | C1 | FP-CGA4J-MFG | CMP-08246-000753-1 | 1
0.1uF | CAP CER 0.1UF 25V X7R 0805 | C2 | FP-CC0805-0_85-MFG | CMP-1036-04410-2 | 1
4.7uF | Chip Multilayer Ceramic Capacitors for General Purpose, 1206, 4.7uF, X7R, 15%, 10%, 50V | C3 | FP-GRM31C-0_2-e0_3_0_8-IPC_C | CMP-1037-04923-3 | 1
1uF | Chip Capacitor, 1 uF, +/- 10%, 25 V, -55 to 125 degC, 1206 (3216 Metric), RoHS, Tape and Reel | C4 | CAPC3216X180X50ML20T25 | CMP-2000-04991-1 | 1
10nF | Chip Capacitor, 10 nF, 16 V, 10%, -55 to 125 degC, 0402 (1005 Metric), RoHS, Tape and Reel | C5 | CAPC1005X55X25LL05T10 | CMP-2000-06332-1 | 1
1uF | Cap Ceramic 1uF 35V X7R 10% Pad SMD 0603 +125°C Automotive T/R | C6 | FP-CGA3E-0_3-0_1-MFG | CMP-08246-002551-1 | 1
1nF | Cap Ceramic 1nF 50V X7R 10% Pad SMD 0402 +125°C Automotive T/R | C7 | FP-CGA2B-MFG | CMP-08246-002303-1 | 1
10uF | Chip Capacitor, 10 uF, +/- 10%, 16 V, -55 to 125 degC, 1206 (3216 Metric), RoHS, Tape and Reel | C8, C9, C10 | CAPC3216X180X55LL20T25 | CMP-2000-06352-1 | 3
3.3nF | Cap Ceramic 3.3nF 50V X7R ±10% SMD 1206 +125°C Embossed T/R | C11 | FP-CL31-IPC_C | CMP-13271-001980-1 | 1
SSW-104-02-G-S | SSW-104-02-G-S Board to Board & Mezzanine Connectors Tiger Buy Socket Strip with PCB Tails, .100 Pitch | J1 | FP-SSW-104-02-G-S-MFG | CMP-00575-00296407-1 | 1
220nF | 74437529203221 WE-HCF High Current Inductor, 220uH, 8.8A, 2.8MHz, 36.45mOhm | L1 | WE-HCF_2920 | CMP-03913-88969860-2 | 1
1.54K |  | R0 | RESC2013X70X40LL20T20 | CMP-2001-04443-1 | 1
3K | Res Thick Film 0805 3kO 1% 0.125W ±100ppm/°C Molded SMD T/R | R1, R2 | FP-RC2012-MFG | CMP-13261-005524-1 | 2
50R |  | R3 | RESC2013X70X40LL20T20 | CMP-2001-00425-1 | 1
215 |  | R5 | RESC2013X70X40NL20T20 | CMP-2001-00039-1 | 1
294K |  | R6 | RESC1005X40X25LL05T05 | CMP-2002-08443-1 | 1
102K |  | R7, R8 | RESC2013X60X35LL10T20 | CMP-2001-04571-1 | 2
340K | RES Thick Film, 340kO, 1%, 0.063W, 100ppm/°C, 0402 | R9 | FP-CRCW0402-e3-MFG | CMP-2002-08533-2 | 1
100K | RES SMD 100K OHM 1% 1/10W 0603 | R10 | FP-RC0603-0_55-MFG | CMP-2100-03662-2 | 1
62K |  | R11 | RESC1608X55X25NL10T15 | CMP-2000-04104-1 | 1
20K | RES SMD 20K OHM 1% 1/8W 0805 | R12 | FP-RT0805-MFG | CMP-2001-01463-2 | 1
13K |  | R13 | RESC2013X70X40NL20T20 | CMP-2001-04416-1 | 1
1K | Chip Resistor, 1 KOhm, +/- 1%, 0.125 W, -55 to 155 degC, 0805 (2012 Metric), RoHS, Tape and Reel | R14 | RESC2013X70X40ML20T20 | CMP-2001-04375-5 | 1
OPA1641AIDGKT | Sound-Plus High-Performance, JFET-Input Audio Operational Amplifier, 4.5 to 36 V, -40 to 85 degC, 8-pin SOP (DGK8), Green (RoHS & no Sb/Br) | U1 | DGK0008A_N | CMP-0808-00041-2 | 1
TL071CDR | Low-Noise JFET-Input General-Purpose Operational Amplifier, 7 to 36 V, 0 to 70 degC, 8-pin SOIC (D8), Green (RoHS & no Sb/Br) | U2 | D0008A_M | CMP-0017-00391-2 | 1
MA40S4S | ULTRASONIC SENSOR TRANS 40KHZ | U3 | FP-MA40S4S-MFG | CMP-06153-000002-1 | 1
LM5161PWPR | IC REG BCK FLYBCK ADJ 14HTSSOP | U4 | FP-PWP0014A-MFG | CMP-04918-000082-1 | 1

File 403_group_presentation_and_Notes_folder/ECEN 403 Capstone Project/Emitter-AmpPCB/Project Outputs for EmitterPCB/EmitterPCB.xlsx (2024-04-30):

Comment | Description | Designator | Footprint | LibRef | Quantity
08052A471JAT2A | General Purpose Ceramic Capacitor, 0805, 470pF, 5%, C0G, 30ppm/°C, 200V | C1 | FP-0805-L_2_01_0_2-W_1_25-MFG | vds | 1
CL21F104ZAANNNC | CL21 Series 0805 100nF 25V -20/+80% Tolerance Y5V Multilayer Ceramic Chip Capacitor | C2, C3, C4, C5, C11, C12 | FP-CL21-IPC_C | CMP-13271-002094-1 | 6
C0805C103K5RACTU |  | C13 | CAPC2013X88X50LL20T25 | CMP-2007-00266-1 | 1
HMK212BJ103KG-T | Multilayer Ceramic Capacitor 0.01 uF 100V B 10% SMD 0805 T/R | C14, C15 | FP-0805-L_2_0_0_1-W_1_25-IPC_B | CMP-14477-005128-2 | 2
EMK107B7105KA-T | None | C16, C17, C18, C19, C20, C21 | FP-0603-L_1_6_0_1-W_0_8_0-IPC_C | CMP-14477-000018-3 | 6
GRM21BR61E106MA73L | Chip Multilayer Ceramic Capacitors for General Purpose, 0805, 10uF, X5R, 15%, 20%, 25V | C22 | FP-GRM21B-0_15-IPC_A | CMP-06035-013048-1 | 1
GMK212BBJ106KG-T | Multilayer Ceramic Capacitor 10uF 35V X5R 10% SMD 0805 T/R | C23 | FP-0805-L_2_0_0_2-W_1_25-IPC_A | CMP-14477-004821-2 | 1
GRM32ER61C476KE15L | CAP CER 47UF 16V X5R 1210 | C24 | FP-GRM32E-0_3-0_2-IPC_C | CMP-2000-06362-2 | 1
C1608X5R1E106M080AC | CAP CER 10UF 25V X5R 0603 | C25, C26 | FP-C1608-080-IPC_A | CMP-2000-05442-2 | 2
GRM21BR61A226ME44L | Chip Multilayer Ceramic Capacitors for General Purpose, 0805, 22uF, X5R, 15%, 20%, 10V | C27 | FP-GRM21B-0_2-e0_2_0_7-IPC_C | CMP-06035-039918-1 | 1
SBR3U60P1-7 | DIODE SBR 60V 3A POWERDI123 | D1 | FP-PowerDI123-MFG | CMP-12791-000040-1 | 1
B340A-13-F | DIODE SCHOTTKY 40V 3A SMA | D2 | FP-SMA-MFG | CMP-1667-00003-3 | 1
PPPC081LFBN-RC | Female Header, Pitch 2.54 mm, 1 x 8 Position, Height 8.5 mm, Tail Length 3.2 mm, -40 to 105 degC, RoHS, Bulk | J1, J3 | SLIN-PPPC081LFBN-RC_V | CMP-1770-00002-1 | 2
SSW-104-02-G-S | SSW-104-02-G-S Board to Board & Mezzanine Connectors Tiger Buy Socket Strip with PCB Tails, .100 Pitch | J2, J4 | FP-SSW-104-02-G-S-MFG | CMP-00575-00296407-1 | 2
744774118 |  | L1 | WE-PD2_5848 | CMP-0227-00443-2 | 1
RMCF0805JT3K90 | 3.9kΩ ±5% 0.125W 0805 Thick Film Chip Resistor AEC-Q200 compliant | R1 | FP-RMCF0805-IPC_C | CMP-26527-001127-1 | 1
MCR10EZPJ563 | Thick Film Chip Resistor, 0805, 56kΩ, 5%, 200ppm/°C, 0.125W, 150V | R2 | FP-MCR10-IPC_C | CMP-08839-017707-1 | 1
ERJ-6ENF1541V |  | R3 | RESC2013X70X40LL20T20 | CMP-2001-04443-1 | 1
ERJ-6ENF1000V | RES SMD 100 OHM 1% 1/8W 0805 | R4, R5 | FP-ERJ6EN-MFG | CMP-2001-04374-6 | 2
ERJ-6ENF2150V |  | R6 | RESC2013X70X40NL20T20 | CMP-2001-00039-1 | 1
RG2012P-7152-D-T5 | Automotive Metal Thin Film Chip Resistor, 0805, 71.5kΩ, 0.5%, 25ppm/°C, 0.125W, 150V | R7 | FP-RG2012-MFG | CMP-28537-008762-1 | 1
ERJ-6ENF6493V |  | R8 | RESC2013X70X40ML20T20 | CMP-2001-00265-1 | 1
CR0805-FX-1783ELF | Thick Film Chip Resistors 0805 178kΩ 0.125W 1% 100ppm/°C | R9 | FP-CR0805-IPC_C | CMP-07231-003764-1 | 1
CRCW080525K5FKEA | RES Thick Film, 25.5kΩ, 1%, 0.125W, 100ppm/°C, 0805 | R10 | FP-CRCW0805-e3-IPC_A | CMP-2001-03724-2 | 1
CRCW0402102KFKED |  | R11 | RESC1005X40X25ML05T05 | CMP-1011-00737-2 | 1
CRCW040225K5FKED | RES Thick Film, 25.5kΩ, 1%, 0.063W, 100ppm/°C, 0402 | R12 | FP-CRCW0402-e3-IPC_A | CMP-2002-08416-2 | 1
AD9850BRS | CMOS, 125 MHz Complete DDS Synthesizer, 10-Bit, Parallel, Serial, RS-28, 47 Tube | U1 | ADI-RS-28_L | CMP-0293-00047-1 | 1
LTC1564CG#PBF | IC FILTR 150KHZ ANTIALIAS 16SSOP | U2 | FP-G-16-05-08-1640-MFG | CMP-0359-00063-3 | 1
MA40S4S | ULTRASONIC SENSOR TRANS 40KHZ | U3, U4, U5 | FP-MA40S4S-MFG | CMP-06153-000002-1 | 3
OPA1641AIDGKT | Sound-Plus High-Performance, JFET-Input Audio Operational Amplifier, 4.5 to 36 V, -40 to 85 degC, 8-pin SOP (DGK8), Green (RoHS & no Sb/Br) | U6 | DGK0008A_N | CMP-0808-00041-2 | 1
TL071CDR | Low-Noise JFET-Input General-Purpose Operational Amplifier, 7 to 36 V, 0 to 70 degC, 8-pin SOIC (D8), Green (RoHS & no Sb/Br) | U7 | D0008A_M | CMP-0017-00391-2 | 1
CD74HC4051MM96EP | Enhanced Product High Speed Cmos Logic Analog Multiplexers/Demultiplexers, D0016A, LARGE T&R | U8 | D0016A_L | CMP-1575-00021-4 | 1
TLV61046ADBVR | IC REG BOOST ADJ SOT23-6 | U9 | FP-DBV0006A-MFG | CMP-04918-000051-1 | 1
LMZM23601SILR | DC DC CONVERTER 1.2-15V | U10, U11 | FP-SIL0010A-MFG | CMP-04918-000359-1 | 2
ASFL1-125.000MHZ-EC-T | XTAL Oscillator 125MHz ±50ppm HCMOS, TTL 3.3V 4-SMD 5mm x 3.2mm | Y1 | FP-ASFL1-MFG | CMP-27762-003537-1 | 1

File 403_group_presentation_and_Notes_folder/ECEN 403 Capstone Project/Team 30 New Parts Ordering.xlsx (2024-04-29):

Order Date | Part Number | Item Name | Location To Buy From | Cost per Part | Quantity | Total Cost
2024-02-22 |  | AD9850 | https://www.amazon.com/HiLetgo-AD9850-Generator-0-40MHz-Equipment/dp/B01J7XPWNU?hvadid=642093301899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 | 20.99 | 1 | 20.99
2024-02-22 |  | Jetson Nano | 102110417 Seeed Studio | Mouser (https://www.mouser.com/ProductDetail/Seeed-Studio/102110417?qs=GBLSl2AkirvPHH3zEMuZ5w%3D%3D) | $186.24 | 1 | $186.24

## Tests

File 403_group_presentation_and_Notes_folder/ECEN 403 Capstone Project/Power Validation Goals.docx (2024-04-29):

- Voltage regulator outputs desired voltage and amps when receiving a voltage signal (2/23)
- Battery charger charges battery when wall power is applied (2/26)
- Battery charger connects battery voltage to voltage regulator when only battery power is applied (2/28)
- Fuel gauge accurately tracks battery fuel (3/3)
- Fuel gauge successfully communicates with MCU using I2C connection (3/3)
- Fuel tracking outputs to screen display (3/17)

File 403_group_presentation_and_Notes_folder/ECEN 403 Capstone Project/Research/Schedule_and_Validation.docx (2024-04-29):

Smart Pest Repeller

Andrew Albritton

Michael McNeil

Melquisedec Ordonez

Schedule and Validation

REVISION – Draft

Interface Control Document

for

Smart Pest Repeller

Prepared by:

_____________________________

Author Date

Approved by:

_____________________________

Project Leader Date

_____________________________

John Lusher II, P.E. Date

_____________________________

T/A Date

Change Record

Rev. | Date | Originator | Approvals | Description
0 | 9/25/23 | ALL | | Draft Release

Schedule:

Work | Start Date | Owner | Status | Date to be Completed
CONOPS | 9/12/23 | ALL | Done | 9/14/23
FSR | 9/25/23 | ALL | Done | 9/28/23
ICD | 9/25/23 | ALL | Done | 9/28/23
Order Project Parts | 10/2/23 | ALL
Midterm Presentation | 9/24/23 | ALL | Done | 9/25/23
Acquire Data-Sets for Training | 9/25/23 | Andrew | | 10/9/23
YOLOv5 implementation on PC | 10/2/23 | Andrew | | 10/9/23
Power PCB Design Complete | 9/29/23 | Michael | | 10/9/23
Finalize PCB for Emitter Unit | 10/2/23 | Mel | | 10/16/23
Status Update Presentation | 10/?/23 | ALL | | 10/12/23
Generate Signals | 10/11/23 | Mel | | 10/13/23
Send Signals to Emitter | 10/16/23 | Mel | | 10/20/23
Train YOLOv5 model | 10/9/23 | Andrew | | 10/23/23
Power PCB Assembly | 10/10/23 | Michael | | 10/28/23
Implement YOLOv5 model on Coral board | 10/23/23 | Andrew | | 10/30/23
Implement Emitter on PCB | 10/23/23 | Mel | | 10/30/23
Power PCB Circuit Testing | 10/29/23 | Michael | | 11/6/23
Set up camera with motion sensor | 10/30/23 | Andrew | | 11/6/23
Develop control logic for post processing | 10/30/23 | Andrew | | 11/10/23
Final Presentation | 10/30/23 | ALL | | 11/2/23
Complete Processing Subsystem Validation | 11/10/23 | Andrew | | 11/20/23
Final Demo | 9/12/23 | ALL | | 11/20/23
Final Report | 11/20/23 | ALL | | 11/27/23

Validation Plan:

Task | Specification | Result | Owner
Training Verification | Goal of 90%>= precision or Goal of .1 >= loss | PASS | Andrew
Camera Verification | make sure 3 photos are taken per second | | Andrew
Motion Verification | Ensure camera activates from motion control | | Andrew
Camera MLA processing verification | Ensure precision is maintained post- implementation (Generalization of model usually yields 10-20% lower probability of detection) | | Andrew
DC/DC Voltage Converter Verification | Verify that converter can take in various input voltages and continue to output 5V and 2A | | Michael
Battery Charger Verification | Verify battery charger charges battery | | Michael
Fuel Gauge Indicator Verification | Verify fuel gauge tracks fuel and indicates when batteries need to charge | | Michael
Power PCB Verification | Verify PCB circuit connects and system functions as intended | | Michael
Signal Verification | Establish signal generator can produce the three separate frequencies required | | Mel
Amplifier Verification | Verify signal is appropriately amplified before reaching emitter | | Mel
Emitter verification | Make sure emitter can emit required frequencies | | Mel
Emitter PCB verification | Verify circuit behaves like individually verified componentes did | | Mel

Schedule and Validation document Revision - 0 Smart Pest Repeller

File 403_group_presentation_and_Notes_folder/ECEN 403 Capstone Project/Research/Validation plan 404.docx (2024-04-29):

Mel do u have anything you want to add to this before i put it in the presentation?

Paragraph # | Test Name | Success Criteria | Methodology | Status | Responsible Engineer
3.2.1.2 | Detection Probability | The model must be able to predict with accuracy =< 90% | Each species will be tested 20 times for detection for probability values | Untested | Andrew Albritton
3.2.5 | Failure Propagation | When the motion sensor is triggered by a species not of interest, there shall be no frequency emitted | Test detection with persons present or with empty background, and see if the emitters turn on | PASS | Andrew Albritton
3.2.5.1.1 | BIT Test | The built in test shall prevent false detections by running post processing on provided images yielding an accuracy of at least 90% (3.2.1.2) | Using the on board camera 50 images are taken. Their confidence and volume of detection are compared to provide a score to prevent false detections | PASS | Andrew Albritton
3.2.3.2.1 | Signal emission post detection | After a species has been detected the Emitter subsystem shall emit a frequency corresponding to the organism | Using a receiver we will measure the output frequency from our emitter subsystem while running the model for classification | PASS | Melquisedec Ordonez
3.2.3.1.3 | Power PCB Output | Subsystem outputs 5V 2A signal while under power | Use a multimeter to measure and track system outputs over various inputs. | PASS | Michael McNeil
3.2.3.1.4 | Battery Charger Output | Charger uses 7.2V signal to charge battery. | Use e load to test the output at the battery connections while under wall power | PASS | Michael McNeil
3.2.3.1.6 | PCB Subsystem Operation | PCB is able to output power while simultaneously managing the battery, from both sources of power. | Complete various test under wall power and battery power and while under only battery power and test each part for proper functionality in that state | PASS | Michael McNeil
3.2.1.1 | Signal Emission Amplification | Upon detection of the three different categories of pest the system will amplify the signal from emitter to at least 7V/V | The output of the amplifier will be measured by an oscilloscope probe along with the input signal coming from the emitter and compared. | PASS | Melquisedec Ordonez
3.2.3.1.1 | Power Consumption | The emitter can be powered by just the power PCB. | Use any power inputs needed by the emitter directly from the power pcb instead of MCU and observe if emission is detectable by ultrasonic detector per 3.2.3.2.1 guidelines. | PASS | Michael McNeil
3.2.4.4 | Full System Validation in garden environment (scenario) | The full system will be able to detect motion and deter detected pests after being turned on. | The user will only have access to a single on off switch. Whenever the user turns the device on it will immediately begin sensing motion and if motion is detected run detection. When presented with all of the differing animal types we will check if the device emits the correct frequency with a portable spectrum analyzer. This will be done in a garden environment to simulate the anticipated application of this product. | PASS | Andrew Albritton

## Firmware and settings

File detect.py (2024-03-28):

import os
import sys
import argparse
import logging
import time
from pathlib import Path
import glob
import json
import moviepy.video.io.ImageSequenceClip #still need to download on coral board <<<<<<
from PIL import Image, ImageFile
import numpy as np
from tqdm import tqdm
import cv2
import yaml
import shutil

logging.basicConfig(level=logging.INFO)
logger = logging.getLogger(__name__)

from edgetpumodel import EdgeTPUModel
from utils import resize_and_pad, get_image_tensor, save_one_json, coco80_to_coco91_class

if __name__ == "__main__":
 
    parser = argparse.ArgumentParser("EdgeTPU test runner")
    parser.add_argument("--model", "-m", help="weights file", required=True)
    parser.add_argument("--bench_speed", action='store_true', help="run speed test on dummy data")
    parser.add_argument("--bench_image", action='store_true', help="run detection test")
    parser.add_argument("--conf_thresh", type=float, default=0.25, help="model confidence threshold")
    parser.add_argument("--iou_thresh", type=float, default=0.45, help="NMS IOU threshold")
    parser.add_argument("--names", type=str, default='data/coco.yaml', help="Names file")
    parser.add_argument("--image", "-i", type=str, help="Image file to run detection on")
    parser.add_argument("--device", type=int, default=0, help="Image capture device to run live detection")
    parser.add_argument("--stream", action='store_true', help="Process a stream")
    parser.add_argument("--bench_coco", action='store_true', help="Process a stream")
    parser.add_argument("--coco_path", type=str, help="Path to COCO 2017 Val folder")
    parser.add_argument("--quiet","-q", action='store_true', help="Disable logging (except errors)")
        
    args = parser.parse_args()
    
    if args.quiet:
        logging.disable(logging.CRITICAL)
        logger.disabled = True
    
    if args.stream and args.image:
        logger.error("Please select either an input image or a stream")
        exit(1)
    
    model = EdgeTPUModel(args.model, args.names, conf_thresh=args.conf_thresh, iou_thresh=args.iou_thresh)
    input_size = model.get_image_size()

    x = (255*np.random.random((3,*input_size))).astype(np.uint8)
    model.forward(x)

    conf_thresh = 0.25
    iou_thresh = 0.45
    classes = None
    agnostic_nms = False
    max_det = 1000

    if args.bench_speed:
        logger.info("Performing test run")
        n_runs = 100
        
        
        inference_times = []
        nms_times = []
        total_times = []
        
        for i in tqdm(range(n_runs)):
            x = (255*np.random.random((3,*input_size))).astype(np.float32)
            
            pred = model.forward(x)
            tinference, tnms = model.get_last_inference_time()
            
            inference_times.append(tinference)
            nms_times.append(tnms)
            total_times.append(tinference + tnms)
            
        inference_times = np.array(inference_times)
        nms_times = np.array(nms_times)
        total_times = np.array(total_times)
            
        logger.info("Inference time (EdgeTPU): {:1.2f} +- {:1.2f} ms".format(inference_times.mean()/1e-3, inference_times.std()/1e-3))
        logger.info("NMS time (CPU): {:1.2f} +- {:1.2f} ms".format(nms_times.mean()/1e-3, nms_times.std()/1e-3))
        fps = 1.0/total_times.mean()
        logger.info("Mean FPS: {:1.2f}".format(fps))

    elif args.bench_image:
        logger.info("Testing on Zidane image")
        model.predict("./data/images/zidane.jpg")

    elif args.bench_coco:
        logger.info("Testing on COCO dataset")
        
        model.conf_thresh = 0.001
        model.iou_thresh = 0.65
        
        coco_glob = os.path.join(args.coco_path, "*.jpg")
        images = glob.glob(coco_glob)
        
        logger.info("Looking for: {}".format(coco_glob))
        ids = [int(os.path.basename(i).split('.')[0]) for i in images]
        
        out_path = "./coco_eval"
        os.makedirs("./coco_eval", exist_ok=True)
        
        logger.info("Found {} images".format(len(images)))
        
        class_map = coco80_to_coco91_class()
        
        predictions = []
        
        for image in tqdm(images):
            res = model.predict(image, save_img=False, save_txt=False)
            save_one_json(res, predictions, Path(image), class_map)
            
        pred_json = os.path.join(out_path,
                    "{}_predictions.json".format(os.path.basename(args.model)))

        with open(pred_json, 'w') as f:
            json.dump(predictions, f,indent=1)
        
    elif args.image is not None:
        logger.info("Testing on user image: {}".format(args.image))
        model.predict(args.image)
        
    elif args.stream:
        logger.info("Opening stream on device: {}".format(args.device))
        
        cam = cv2.VideoCapture(args.device)
        photos = 0
        while photos < 51:
          try:
            res, image = cam.read()
            photos = photos + 1
            if res is False:
                logger.error("Empty image received")
                break
            else:
                full_image, net_image, pad = get_image_tensor(image, input_size[0])
                pred = model.forward(net_image)
                photo_name = str(photos)
                imagepath = "out_images_/"+photo_name+".jpg"
                model.process_predictions(pred[0], full_image, pad, output_path=imagepath)
                ImageFile.LOAD_TRUNCATED_IMAGES = True
          
                tinference, tnms = model.get_last_inference_time()
                logger.info("Frame done in {}".format(tinference+tnms))
             
          except KeyboardInterrupt:
            break
                    
        '''
        fps = 5
        if os.listdir("out_images_"):
          clip = moviepy.video.io.ImageSequenceClip.ImageSequenceClip("out_images_/", fps=fps)
          clip.write_videofile('my_new_video.mp4')
          folder = 'out_images_/'
          for filename in os.listdir(folder):
            file_path = os.path.join(folder, filename)
            try:
              if os.path.isfile(file_path) or os.path.islink(file_path):
                os.unlink(file_path)
              elif os.path.isdir(file_path):
                shutil.rmtree(file_path)
            except Exception as e: 
              print('Failed to delete %s. Reason: %s' % (file_path, e))
              '''
        cam.release()

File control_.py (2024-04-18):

import os
import pandas as pd
import time
from periphery import GPIO


'''
this file will be used to take in images from our camera
- then send photos through detection using os command
- then pull detected objects from output csv from above line and perform following steps
- average out detection accross the three species of interest
- whichever species that is detected in the most frames will then be sent to the GPI/O pins for transmitter application


***input***
images for detection
off_switch (recieved signal from arduino of system power is to shut down)
(this is needed to accomidate the google coral boards shutdown requirements)

***output*** 
final descision label for transmission 
and SPI/GPIO communication depending on found frequency
'''

W_CLK = GPIO("/dev/gpiochip4",10,"out")         #pin 18
FQ_UD = GPIO("/dev/gpiochip4",12,"out")         #pin 22
DATA = GPIO("/dev/gpiochip0", 7, "out")         #pin 29
RESET = GPIO("/dev/gpiochip0", 8, "out")        #pin 31

def pulseHigh(pin):               		# Function to send a pulse
  pin.write(True)
  pin.write(True)
  pin.write(True)
  pin.write(False)# do it a few times to increase pulse width# (easier than writing a delay loop!)   	# end of the pulse
  return

def tfr_byte(data):               		# Function to send a byte by serial "bit-banging"
  for i in range (0,8):
    if((data & 0x01) == 0x01):	# Mask out LSB and put on GPIO pin "DATA"
      DATA.write(True)
    elif((data & 0x01) == 0x00):
      DATA.write(False)
    pulseHigh(W_CLK)              	# pulse the clock line
    data=data>>1                  	# Rotate right to get next bit
  return

def sendFrequency(frequency):     		# Function to send frequency (assumes 125MHz xtal)
  freq=round((frequency*4294967295)/125000000)
  print(freq)
  for b in range (0,4):
    tfr_byte(freq & 0xFF)
    freq=freq>>8
    
  tfr_byte(0x00)
  pulseHigh(FQ_UD)
  return


# Getting file_names_array using this function
def get_file_names(folder_path):
    try:
        # Get a list of files in the specified folder
        file_names = os.listdir(folder_path)

        # Filter out subdirectories and keep only file names
        file_names = [file for file in file_names if os.path.isfile(os.path.join(folder_path, file))]

        return file_names
    
    except OSError as e:
        print(f"An error occurred: {e}")
        return []


###
'''
insert code here to use above functions for image processing
'''

# GPIO pin initialization
motionsensor = GPIO("/dev/gpiochip4", 13, "in")  # pin 36
off_switch = GPIO("/dev/gpiochip0", 6, "in") # pin 13
blueLED = GPIO("/dev/gpiochip2", 9, "out") # pin 16
yellowLED = GPIO("/dev/gpiochip2", 13, "out") # pin 37
counter = 0
try:
    while True:
        try:
            state = motionsensor.read()
            turn_off = off_switch.read()
            print("waiting for motion")

            if turn_off:
                os.system("sudo shutdown now") #turns system off when switch is turned
            if state:
                print("Motion Detected! Running Classification...")
                os.system("python3 detect.py -m final_weights-int8_edgetpu.tflite --names data.yaml --conf_thresh 0.3 --stream --device 1")
                time.sleep(3.0)
                dataframe = pd.read_csv("detections.csv", header=None)   
                length = dataframe.shape[0]
                found_labels = dataframe.loc[0:length, 0]
                found_probs = dataframe.iloc[0:length, 1]
                found_probs = found_probs.to_numpy()
                flycount = 0.
                flyprob = 0.
                lizardcount = 0.
                lizardprob = 0.
                rodentcount = 0.
                rodentprob = 0.
                foundfly = False
                foundliz = False
                foundrat = False
                ratscore = 0.
                flyscore = 0.
                lizardscore = 0.
                #counts of each category requireing frequency emission
                #possible labels - names: ['0', 'Dogs', 'Fruitfly', 'Human Body', 'Lizards', 'Squirrel', 'aphid', 'fly', 'kid', 'person', 'rat']
                
                for i in range(0, len(found_labels) - 1):
                    condition = found_labels.iloc[i]
                    condition = str(condition)
                    if condition in ['Fruitfly', 'fly', 'aphid']:
                        flycount += 1
                        flyprob += found_probs[i]
                        foundfly = True
                                        
                    elif condition in ['Lizards', '0']:
                        lizardcount += 1
                        lizardprob += found_probs[i]
                        foundliz = True
                                    
                    elif condition in ['Squirrel', 'rat']:
                        rodentcount += 1
                        rodentprob += found_probs[i]    
                        foundrat = True 
                
                #averaging scores
                if (foundrat == True):
                    ratscore = rodentprob / rodentcount
                if (foundfly == True):
                    flyscore = flyprob / flycount
                if (foundliz == True):
                    lizardscore = lizardprob / lizardcount
                
                scorelist = {'rat':ratscore, 'lizard':lizardscore, 'fly':flyscore} # score is used to display confidence, however during testing it was found that 
                countlist = {'rat':rodentcount, 'lizard':lizardcount, 'fly':flycount} # count is a more effective way to process images with detected items with an accuracy increase of 20%
                tot_count = max(countlist, key=countlist.get)
                descision = max(scorelist, key=scorelist.get)
                if (foundrat == False and foundfly == False and foundliz == False): 
                     print("no object detected, checking for motion...")
                else:
                    print("rat averaged    prob: ", ratscore,'\n')
                    print("lizard averaged prob: ", lizardscore, '\n')
                    print("fly averaged    prob: ", flyscore, '\n')
                    print("Transmit Frequency: "+tot_count)
                    if (tot_count == 'rat'):                # both on
                        yellowLED.write(True)
                        blueLED.write(True)
                        frequency = 70000               		# choose frequency and
                        pulseHigh(RESET)                  		# start-up sequence...
                        pulseHigh(W_CLK)
                        pulseHigh(FQ_UD)
                        print("sending frequency: "+str(frequency))
                        sendFrequency(frequency)          		# start the oscillator
                        
                    if (tot_count == 'lizard'):             # blue on 
                         blueLED.write(True)
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

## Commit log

2024-03-06 Create SPI_test.py
    will be used to test coral board's SPI communication
2024-03-06 Update SPI_test.py
    This will test coral board spi
